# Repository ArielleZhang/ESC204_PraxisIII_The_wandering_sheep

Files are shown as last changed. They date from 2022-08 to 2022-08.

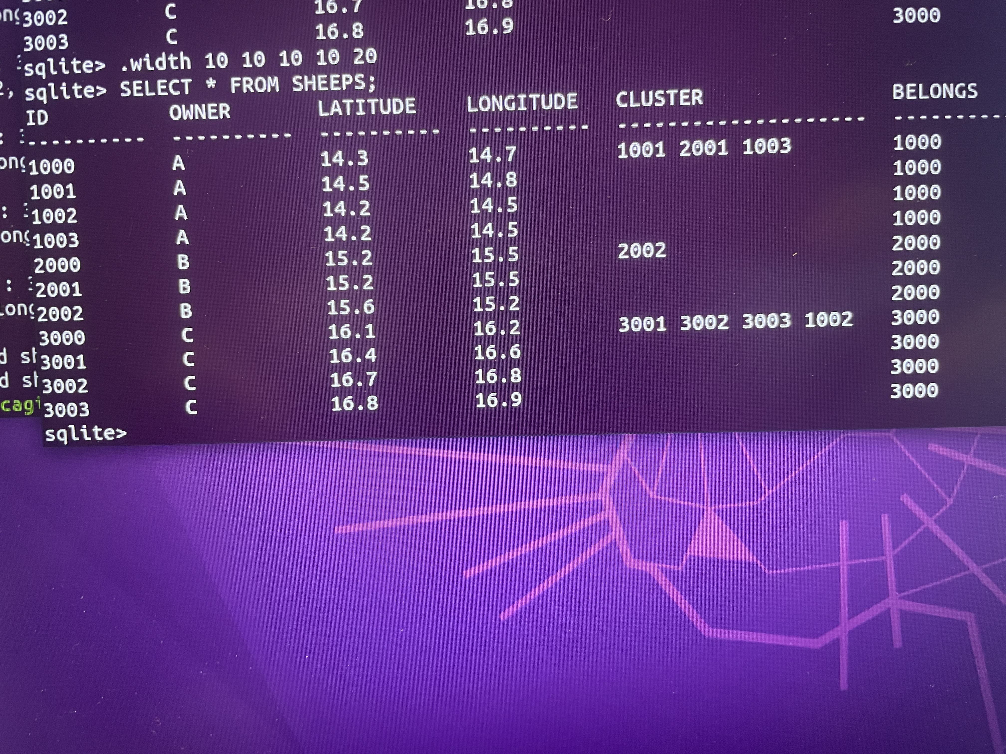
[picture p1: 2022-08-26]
Design Milestones/Prototype/Back End/Second Version/database_pic.jpg

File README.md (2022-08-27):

# ESC204_PraxisIII_The-wandering_sheep

Design considerations
The wandering sheep project implemented the "Improving GSM-based sheep tracking: Using a cluster-based multi-hop approach" paper to develop a cost efficient but accurate sheep tracking system for residents in Rosedale, Mthatha, South Africa.

## Electrical requirements
1. Go to /Follower Sheep(Wireless Transceiver), download the adafruit library zip.
2. Add it to the arduino libraries file, open files->examples->adafruit blue fruitLE nF51->blueart_cmdmode.
3. Uncomment the software UART in the code, comment the default SPI code.
4. Download the Blue Connect mobile phone app, connect it to the bluefruit device.
5. Upload to the board and open the serial monitor.
6. If upload failed, check the serial port, make sure it's the arduino UNO port.

## Collar design requirements
1. The CAD model files of the collar design is in /Physical Collar.

## Back end requirements
1. The back end database with an example used in the demo video is in /Backend Database.

## PM documentations and the final deliverables
1. The PM artefacts are in /Team Process (formal checkin documents), and /Housekeeping.
2. There are two main deliverables, the Proposal and the Pitch, relavent documents are in /Design Milestones.

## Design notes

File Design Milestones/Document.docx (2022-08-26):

MAX 12 Pages + 5 appendix + 3-5 team description + bill of material 12 points, times new roman, 1.15, number all pages‼!

## Table of Contents:

I. Executive summary
II. Introduction
III. Background
  a. Scoping
  b. Team Values
  c. Reference Designs
  d. Requirements model
IV. Design Process
  a. Key Decisions for Conceptual Design
  b. Key Decisions for the Prototype
  c. Verification (backend testing cases table need to be edited)
  d. Validation
  e. Reference Designs
  f. GSU reflection
V. Discussion of the Final Outcome (need to cut length and edit)
VI. Conclusion

Appendix I. Teams (Emre’s team member description)

Appendix II. BOM

References

## I. Executive Summary

In Mthatha, South Africa, many farmers face problems with missing sheep. It is tedious work to look for the missing sheep as neither the shepherds nor the farmers have cars and information on where the sheep are. Therefore, they are looking for a cost effective solution to make finding missing sheep easier. As a team, our values are empathy, sustainability, functionality, and accessibility. Our scope was to make a reliable sheep tracking system that is accessible to everyone from the community to prevent the sheep from wandering off or mixing with other flocks. When addressing this opportunity, we prioritized the perspective of the stakeholders. In the opportunity overview, it was stated that “The livestock owners would benefit from a cost-effective solution to track their animals and find them when lost.” Stakeholder analysis gives us the two prioritized objectives: cost efficiency and functionality to track the sheep. The prioritization of these two values scoped out alternatives such as geo-fencing and thermal imaging with drones. Because fencing lacks the functionality to track sheep and thermal imaging with drones has excessive cost that cannot be afforded by the stakeholders. In the end, we decided to use Global System for Mobile (GSM) and Global Positioning System (GPS) to track the sheep with a clustering system which satisfied both of our prioritized objectives. GSM allows for transmission of data through a 2G cellular network, which was chosen since the infrastructure exists to support this system in Rosedale. We divided the flock into small groups, called clusters, with each cluster having a leader sheep with a GPS tracker to locate the cluster. Each leader sheep pings the followers within the cluster based on the Received Signal Strength Indication (RSSI), and the followers reply with their ID which is unique for each sheep using the wireless transceivers. After getting each follower sheep, every leader sheep sends the information to the database using GSM. The clustering algorithm is used to detect missing sheep, and if there are any, those sheep will be displayed in the User Interface (UI) with their ID, the most recent location and missing time. The customized color and engraved sheep ID on the tracker allow the stakeholders to easily identify and differentiate their sheep when looking for them. Our design made a delicate balance between cost efficiency and functionality by reducing the GPS modules needed, assuming that most of the leader sheep will be evenly distributed among the flock.

-add sustainability stuff

## II. Introduction

Small sheep owners in the small town of Rosedale, Mthatha are struggling with retaining their sheep. As livestock farming plays a major role in their economy, losing sheep is critical [1]. There are several situations where a sheep could get lost; They could simply wander off, get mixed up with different owners’ sheep, or could not be taken care of due to the absence of shepherds. Therefore, we and the stakeholders are seeking a solution that has reliable functionalities to track the location of lost sheep such that the loss can be prevented. Here, as the stakeholders include sheep owners and shepherds, the solution must be accessible in terms of cost (one of the most emphasized requirements by the stakeholder), portability, and ease of learning. Furthermore, as our team values sustainability as required by UNSDG 12, therefore a design with a responsible consumption and production process that is durable is also preferred.

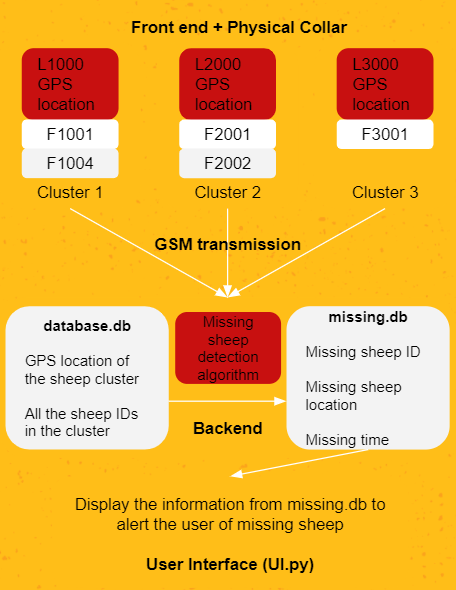
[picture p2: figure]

Figure 1 Sheep_Link conceptual design flowchart

The final proposed design is Sheep_Link, an accessible and reliable Global Positioning System (GPS) Global System for Mobile Communication (GSM) missing sheep tracking system to prevent sheep loss. The system includes electrical GPS GSM tracker collar, backend database and frontend UI. To balance between the two most highlighted high-level requirements by the stakeholders: cost efficiency and functionality of location tracking, we decided to use cluster tracking method. There are two types of sheep trackers for each sheep, leader tracker and follower tracker. Each tracker stores a unique sheep ID: leader’s ID starts with an F, and follower’s ID starts with an L. Both types have wireless transceivers but only leader sheep has GPS GSM module to gather the location and transmit information to the backend database. When updating, leaders ping nearest followers based on the Received Signal Strength Indicator (RSSI), and followers respond by sending their IDs to the leader. Leader sends all the cluster IDs and its own current GPS location to the backend database. The cluster size is customizable depending how many leader trackers the user wants, having smaller cluster size provides more accurate location tracking with a trade-off to be a higher cost because GPS GSM module is the relatively expensive part of the tracker. Backend clustering algorithm will send missing sheep alerts including missing sheep location and missing time through the User Interface (UI) whenever a missing sheep is detected. Also, keeping the UNSDG 12 in mind, we designed the physical tracker to be using recyclable polymer [2], and rechargeable batteries

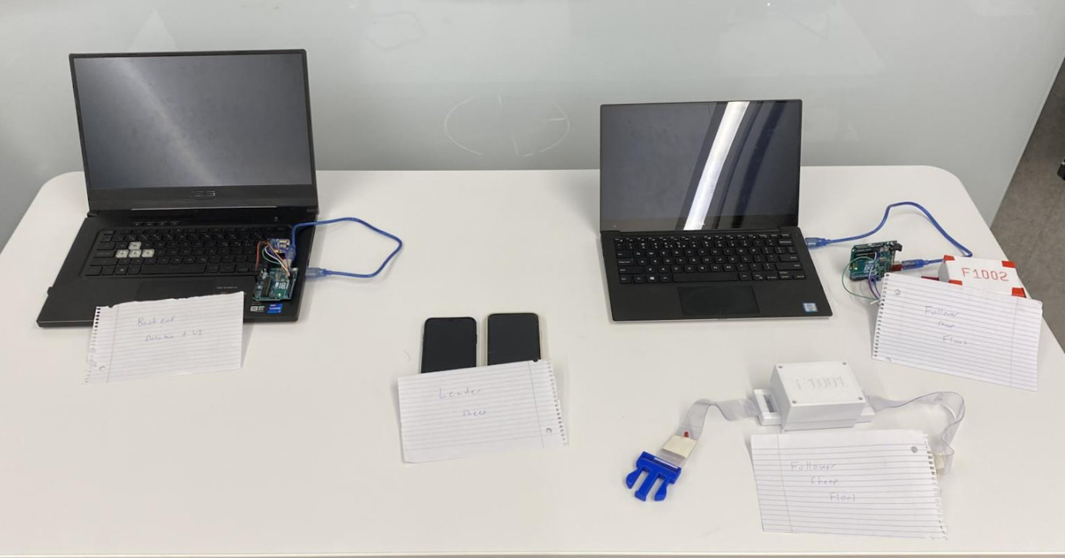
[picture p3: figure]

Figure 2 Final prototype of the trackers and the backend

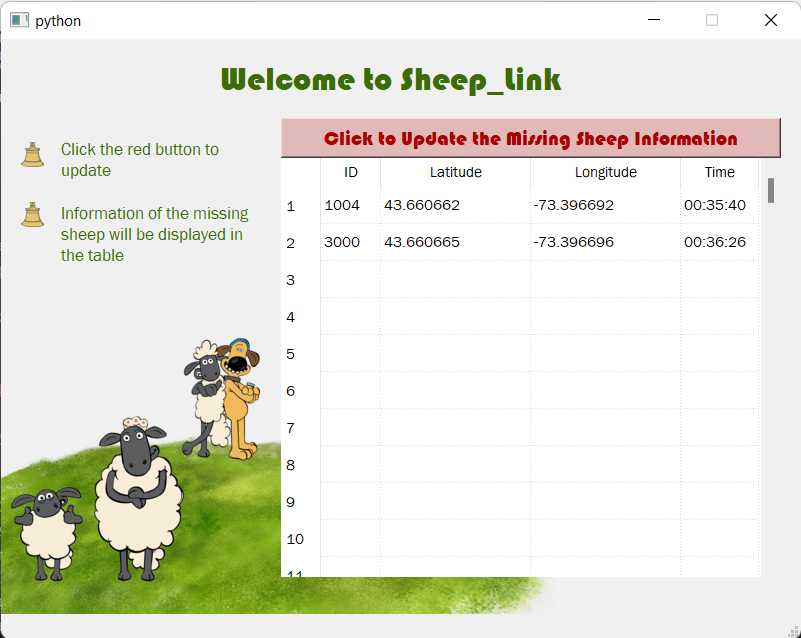
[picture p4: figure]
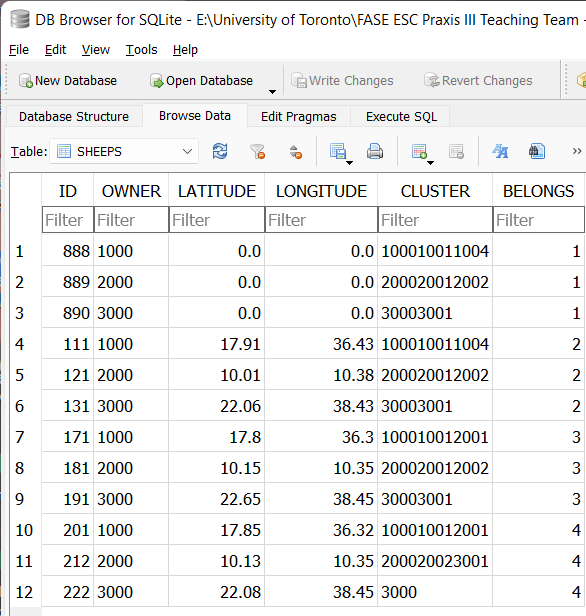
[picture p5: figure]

Figure 3 Final prototype of the UI and backend database

We prototyped two fully functional follower trackers (F1001 and F1002 in Figure 2) with Bluefruit LE UART Friend and Arduino UNO R3. F1001 is powered by a 9V battery, and it has a complete case concealing the electronics with an adjustable belt strap. F1002 is powered by the laptop. With the available components in MyFab, we could only use Bluetooth transceivers with UART protocols. However, Bluefruit comes with a phone app that supports multiple UART modes, allowing us to ping several follower trackers at the same time. The GPS location of the phone is also available on the Bluefruit app. Therefore, we decided to use the phone as the leader sheep although there are other choices for us to proxy. Because the Bluefruit app is the best possible representation of the system. After being pinged by the leader, F1001 and F1002 will send their IDs to the Bluefruit app via UART. Since GSM module is not available in MyFab, we proxied by manually sending the received follower IDs and the GPS location to the backend database (the left laptop in Figure 2) also using the Blurfruit LE UART Friend. The backend database and UI (Figure 3) is fully developed using SQLite and python. The algorithm can detect both missing leader and follower. The UI displays all important information including missing location and missing time of the missing sheep. The UI is also designed for better accessibility: available in both English and Xhosa and requires no technical training. The final prototype for one collar costs us: Arduino UNO R3 ($24.95) + Bluefruit ($17.50) + Battery ($3.7) + 3D printed tracker case and collar strap ($3.50) = $49.65.

1. (Ethan)Select Background Details (we could copy and paste from the proposal for this part)
  a. Understanding the stakeholders:
    i. Who is affected and how?
    ii. What is the value for stakeholders?
  b. Defining the scope:
    i. What are the limits to what we can do (and not do)?
    ii. What is the primary goal of your team’s design? Provide details explaining the value proposition of your team’s design (i.e., benefits to the stakeholder and how these relate to the UN Sustainable Development Goals.[1])
  c. Describing the service environment:
    i. What is the situation in which it must work?
    ii. What additional considerations and/or complications are added by the environment?
  d. Describe previous approaches to providing value in this or similar contexts:
    i. Making reference to previous solutions, reference designs, and literature.
    ii. Examining what was previously tried.
    iii. Assessing how well did it work.
  e. Are there specific standards or details that any solution must meet?

## III. Background

## Stakeholders

The sheep owners in the rural town of Rosedale, Mthatha are the primary stakeholders. The main factors that affect the stakeholders are the economic impacts due to the lost sheep, the effort required on their end for finding the sheep, and the accessibility of the product. The three corresponding values are economic, convenience, and accessibility. The stakeholders wish to secure their profit by finding the lost sheep, so it would be illogical to spend more funds on finding sheep compared to the gain. Furthermore, tracking the lost sheep takes effort on the owners’ end as currently, they need to search the vicinity usually 1-2 km away or nearby homesteads up to 5 km away without cars. Therefore, functionalities such as accurate tracking and locating of the lost sheep can bring the value of convenience to the stakeholders. Lastly, to maximize benefits for most sheep owners, accessibility is highly valued. Considering the technical abilities of the shepherds, implementing the solution should be easy for the shepherds to handle. In this proposal, we prioritize the needs and values of our primary stakeholders; however, secondary stakeholders such as shepherds and sheep are also important. The shepherds are underpaid and are often given a high workload; thus the owners have a precarious relationship with the shepherds. Reducing the shepherd’s workload by introducing high functioning designs that can motivate them to work, would secure the owners’ money by minimizing the chances of sheep getting lost. For the sheep, the solution should not reduce the economic value of the sheep both directly and indirectly, thus the solution should not harm the sheep.

## Scoping

With the internet and mobile network coverage, the assistance of shepherds, and the limitations on funding, our scope is to develop a reliable sheep tracking system that is accessible to every community member in Rosedale, which can prevent sheep from wandering off or mixing up with other flocks. The focus of the design will be its reliability to prevent the sheep from wandering off and its feasibility of being integrated into the daily lives of the shepherd.

## Team Values

Our teams had three main values that will be incorporated into the requirements model: Functionality, Accessibility and Sustainability. Functionality is one of the main priorities of the design since the shepherds are looking for a design that will address the issue of wandering sheep. This will include tracking capabilities and a system that is accurate and accounts for all possible instances of sheep wandering off. Additionally, in our teams’ values, we incorporate empathy into the design in the form of accessibility. We focus on making the product accessible to everyone in the community by keeping the cost affordable and making it easy to learn and operate. Aiming to make the system highly automated and user-friendly streamlines the training process, providing ease of learning for shepherds and sheep owners. In keeping with the 12th goal of UNSDG, sustainable consumption and production in mind, we aim to make the design durable to improve resource usage efficiency. The extended lifetime of the product reduces the cost for the stakeholders and is identified as responsible consumption promotion.

## Reference Designs

Fencing (sometimes electrified) is a popular option for animals wandering off problems. Fencing an area is simple and effective to prevent animals from leaving by creating a physical barrier. However, for our stakeholders, it is not a valid solution. Because many shepherds in Rosedale share a communal grazing area, the coordination of fencing would be complicated, and fencing would reduce the amount of grazing land the shepherds have. Price estimates to be 7500 – 15000 USD (9500-19000 CAD) for the amount of grazing land the shepherds have, which is very expensive when compared to the price requirements provided later [3]. Taking fencing as a reference design, the cost of our solution should be lower than this. Another option that has been used to find sheep is GPS tracking. This has been used for sheep tracking in countries such as Norway [4]. The Telespor system is the current “market-leading" solution and makes use of a GSM to locate sheep in real time. However, this is also costly at 290 CAD per sheep, with no flexibility since each sheep’s collar will make use of GPS technology [5].

## Requirements

The requirements model was developed to fulfil the needs of our stakeholders by successfully preventing sheep loss and ensuring that the design would be feasible to integrate. We incorporated our value proposition by deriving the high-level objectives from the three values. From each high-level objective, we developed detailed objectives to be our specific testing protocols. We will first verify each subsystem of our prototype to ensure that there are no errors or malfunctions, and then will validate the design by either physically testing is possible or otherwise theoretically predicting the outcome against each proposed requirement to holistically assess to what extent our design delivers the values to the stakeholders.

Functionality

Location Tracking

The primary functions of the design should include a lost sheep notification system and finding system to fully address the missing sheep issue. The first functionality requirement is that it must track the location of the sheep.

Table 2 Criteria, metrics, and constraints for the finding system

Criteria: tracking range
Farther is better (m) | Must ≥ 2000 m. Should ≥ 5000 m

Criteria: location accuracy: closeness of a measured location to the real location of the device at the time of measurement [6]
The closer is better (m). GPS level accuracy is within 4.9m[7]. | Must not exceed 20m to provide an accurate location of the sheep

Reliability

Reliability requirements make sure that the design can handle the different cases of the sheep wandering off, and that the shepherds can be notified within time to prevent the sheep through action.

Criteria: reliability of the notification communication

Lower percentage error of false alert (%)

Must not be interrupted and interfered with when transmitting messages.

Should allow notification documentation, record all the history notifications [8]

Accessibility

Affordability

The requirement that was emphasized the most by the primary stakeholders was cost-efficiency. The stakeholder provided an ideal cost of 150 * 12 CAD = 1800 CAD for the final product. However, recognizing the challenge to implement solutions with high functionality to accurately and reliably track the sheep's location, we justified cost constraint of the final design to be less than 3400 CAD because the average purchase price of the sheep in South Africa is approximately R1,300 and the average sheep output of small livestock owners is approximately R3,000 [9]. The average profit efficiency of the sheep was estimated to be about 65.5% [9]. Therefore, the strict profit made by each sheep can be estimated to be around R2,000. On average, small livestock owners have 150 sheep, and the rates of sheep loss has an average of 8% [10]. Hence, the minimum loss would be about 12 sheep. Therefore, we set the constraints for the budget to be (the strict profit each sheep makes + the price of the sheep) * (the number of sheep that get lost) as the design should be profitable in the end. Therefore, our hard constraint is that our design must not exceed (R2,000 + R1,300) * 12 ≈ R39,600 = 3410 CAD per year.

Portability

As part of the design for travel and ergonomics, the solution needs to be able to move around freely to track the sheep at different locations. Portability requirements for handheld devices were taken from the 2005 US human factors guide for the design of handheld devices. Two of the main concerns for devices are the weight and dimensions of the device. Note that the dimensions of the device are specified as the stow-away size; some devices may unfold but must stow away to a good size.

Table 3 Criteria, metrics, and constraints for portability

Criteria: Device needs to be easy to move around, and shepherds must be able to use the device over the range of the grazing area (~5km through hilly terrain and villages).
A lighter device is preferred (weight in pounds) | Widgets should be under 5.1 pounds if handheld. [11]
A smaller stowaway volume is preferred (size of dimensions in mm) | Widget should stow away to under 100x125x255mm in size [11].

Ease of Learning

The product should have the option to display information in the local language Xhosa [12]. Since the solution will be implemented with local shepherds, there also needs to be education in teaching them how to use the design solution. The less time it takes for the shepherds to learn how to use the design the better. This will depend on the quality of the user interface and should contain features such as one-click information finding and intuitive graphics.

Sustainability

UN SDG 12: Responsible consumption and production

Responsible consumption and production objectives relate to the materials used for the physical collar [13]. The goal is to use materials that have the smallest carbon footprint and can be recycled if the product were to be taken apart. An additional consideration is the impact of the battery, using rechargeable batteries instead of lithium batteries reduced soil and air contamination [14].

Durability

High durability reduces product costs for the stakeholders by reducing the amount of maintenance needed. Besides the cost, durability also encourages responsible production by increasing resource efficiency. Considering the grazing area is close to water sources, the product needs to be waterproof, dustproof and drop proof.

Criteria: Device needs to work for an extended period without malfunctioning

The lifetime of design [15]

Must pass waterproof and dustproof test from IP5 to IP6 [16]

Must pass drop test for ANSI/ISEA 121-2018 [17]

Working at least two weeks without charging [18]

2. (Arielle)Design Process and Key Design Decisions
1. (Arielle)The path to development of the prototype:
  a. Insights into the presented conceptual design that were gleaned from the prototyping process.
2. (Ethan) Comparison to previous approaches (i.e., reference designs) (i.e., tell the audience why your solution is an appropriate choice in relation to the reference designs).
  a. Mention geofencing, the GPS TLS tracker, RFID scanning, paint/collar

## IV. Design Process and Key Design Decisions

In our project management plan, the team is divided into three divisions: hardware of the tracker, physical design of the collar, and software, which include the backend database and front-end UI. Three engineers from our team are assigned to be the lead of each division, and deadlines for design milestones are set to check the progress of all three divisions and merge the work.

Key decisions for the conceptual design:

1. Use GPS to track the sheep's location:

As required by the stakeholder, they would like to track the exact location of the missing sheep. We interpreted the latent need behind this requirement to be the need to minimize the effort spent when searching for missing sheep. GPS is used to monitor the sheep’s location all the time and notify the shepherds once the sheep leaves the cluster. Notifying the shepherds, the exact location of the wandering sheep before it goes too far away allows the shepherds to efficiently target the wandering sheep and get it back immediately, which reduces the workload. Thus, we believe it is the best solution that satisfies the stakeholder’s needs.

2. Use clustering methods to reduce the cost:

However, the tradeoff for using such expensive GPS trackers is the excessive cost. The stakeholders not only value functionality, but also value cost efficiency. However, we recognized the conflict in satisfying both. The clustering method we introduced in section__ leaves the choice of whether to be cheaper but have a larger location uncertainty or to have a smaller location uncertainty but be more expensive to the stakeholder. (add details about the clustering calculation?)

3. Use GSM to transmit information:

From the context provided by the stakeholders, the town of Rosedale has mobile phone coverage. Furthermore, research has shown that Mthatha has full 2G GSM coverage provided by Vodacom, Telkom, and MTN [19]. GSM network is significantly cheaper than Wi-Fi, 3G, 4G, and 5G networks and therefore reduces the cost. Here, it should be noted that as great as GSM is for increasing affordability, this is in exchange for the speed of the connection. Since the current market is working with the 5th generation of digital networks, GSM being the 2nd generation implies its lack of rapidity. Nevertheless, as 2G network is still integrated into our daily lives, the connection speed is sufficient for this application and if the stakeholders wish for a faster connection, a simple upgrade in the network to 3G or higher is all that is needed.

4. Accessibility of the UI:

To make the product easy to use for the shepherds and sheep owners, we designed the UI to have both English and Xhosa versions. Also, the one-click-to-update feature is very user-friendly, requiring zero technical training.

To demonstrate the full functionality of the conceptual design, we decided to prototype both types of the trackers, the physical collar, the backend database with the UI. These are the three main tasks for the three divisions in our PM plan.

Key decisions for the prototype:

1. We fully prototyped one battery powered follower tracker with the hardware concealed in the complete physical collar to demonstrate the design concepts. The second follower prototype is only powered by the laptop to save batteries (practicing UNSDG 12 responsible production). We decided to prototype two followers because we need to test the clustering functionality based on the RSSI strength.
2. We decided to use Bluefruit Connect phone app as the leader sheep because the app has multiple UART mode, accurately representing the idea of leader sheep calling multiple follower sheep at once. Furthermore, the app allows us to acquire the GPS location of the phone, representing the GPS module to be implemented in the product. The leader communicates with the backend using Bluetooth, which is a proxy of the GSM transmission because MyFab does not have a GSM module. Then we need to manually send the information (GPS and the collected follower IDs) to the backend.
3. We fully prototyped the backend database using SQLite and Python and prototyped the UI using PyQt5. We chose to use database because compared to txt files and excel, SQL database is the most efficient way to store and handle large number of update messages because we need to use python to extract write information into the database to detect missing sheep. We chose to use PyQt5 to write the UI because it is intuitive and widely used.

Influence of Reference Designs on Process

The most relevant reference design that influenced our thinking as a group was the Telespor system from Norway mentioned earlier in the reference design section. The main drawbacks of the solution that made it unsuitable for our opportunity was that it is costly and would be hard to integrate into the shepherd’s operation due to language constraints (the Telespor system is not offered in the local language Xhosa). Our design addresses these two issues by offering flexiblity on how many GPS modules to include, lowering the price point. Additionally, we have designed our UI to be usable in many languages including Xhosa and features such as one-click updates ensure that the design is accessible to the shepherds. However, our design is not as developed as the telespor system, and further improvements on battery life and design of the leader sheep’s collar may increase the price of the design.

Verification

To ensure the high-fidelity prototype is functional, reliable and error-free, we tested each subsystem with repeated trials. We did not integrate the trackers and the backend database because we do not have the GSM transmission module. Using the Bluefruit and the Bluefruit Connect phone app to proxy does not allow the collected information to be automatically sent to the backend.

Electronic Subsystem

To test the electronic pinging system, we needed to test three components:

1. Whether RSSI range can be used for clustering
2. Pinging the sheep and how it responds with the identification number
3. The feasibility of powering the system and running the circuitry with the 9V battery

Testing of the RSSI was done through graphing the RSSI against distance. Through experimentation, it was found that the RSSI strength decays in a non linear fashion.

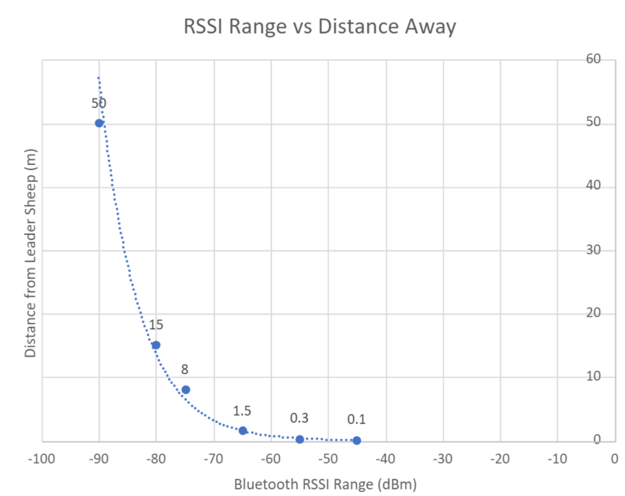
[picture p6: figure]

From this testing, we found that RSSI strength works for clustering, but becomes very unreliable at longer distances since the signal strength falls off quickly. The next set of verification tests we performed are the different cases of pinging sheep. After setting up the follower sheep collars, we used the Bluefruit app to test if we can ping both sheep, and each individual sheep (simulating the case where the other sheep is out of range).

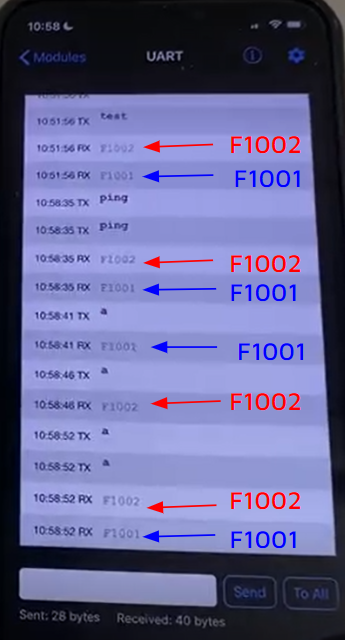
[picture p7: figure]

The results of the test showed that we could ping multiple sheep using the multiple UART function of the app, which gave us confidence in our final design, since we are able to ping all nearby sheep with a single message. Lastly, the arduino was sufficiently powered by the 9V battery and supplied constant power throughout our 1 hour testing sessions. This showed us that the battery life of the prototype was adequate, and can be improved through further research and development.

Physical collar

1. The base of the tracker perfectly fits the Arduino (Figure_), and the Bluefruit and the battery are “soldered” or taped onto the second layer. These all prevent the electronics from moving inside the case even when shaking and/or dropping to the ground from 1-meter height (the standing height of a sheep).

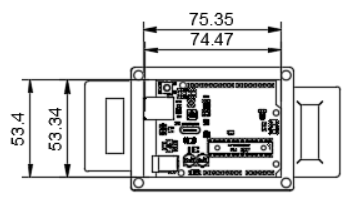
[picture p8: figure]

2. The hardware was found to be fully waterproof such that the tracker inside was safe from any damage when proxy waterproofing in the form of rubber bands was added. This was tested by putting tissues inside the cover and sinking it under water for 2 hours, following the test for waterproof and dustproof level IP5 and IP6.
3. The engraved sheep ID in 3D printing is clear and easy to see.

Backend Database and Clustering Algorithm

The backend algorithm passed all testing cases that would be encountered: no missing sheep, missing follower sheep and missing leader sheep. We created a three-leader sheep flock for this testing, therefore there will be three data entries into the database for each update.

Table 1 Initialized leader sheep and clusters

Leader Sheep ID | Cluster Sheep IDs | Case 0 initializing the database Algorithm output: no missing sheep.
1000 | 1001, 1002, 1003, 1004, 1005
2000 | 2001, 2002, 2003, 2004, 2005
3000 | 3001, 3002
1000 | 1001, 2001, 1002, 1003, 1005 | Case 1: 2001 and 1004 changed clusters Algorithm output: no missing sheep.
2000 | 2002, 2003, 2004, 2005
3000 | 3001, 3002, 1004
1000 | 1001, 2001, 1002, 1003, 1005 | Case 2: missing follower sheep when it leaves the flock Algorithm output: missing sheep 1004, the most recent GPS location of the cluster (sheep 3000’s location), and the missing time.
2000 | 2002, 2003, 2004, 2005
3000 | 3001, 3002
1000 | 1001, 1002, 1003, 1004, 1005 | Case 3: missing leader sheep when it has an empty cluster Algorithm output: missing sheep 3000, the most recent GPS location of 3000, and the missing time.
2000 | 2001, 2002, 2003, 2004, 2005, 3001, 3002
3000

User Interface

The User Interface is a python file, after running, the UI will pop up with a clickable button allowing the user to manually refresh the page. The UI automatically reads the output of the backend clustering algorithm from another database that stores the missing sheep information. One shortcoming of the database is that it does not automatically refresh.

Validation Chart

To ensure the high-fidelity prototype is delivering the values (functionality, accessibility and sustainability) we would provide to the stakeholders, we assessed and/or tested the prototype against each detailed objective.

Functionality

Criteria: tracking range

GPS has global coverage, allowing sheep to be tracked anywhere in the world.

Criteria: location accuracy: closeness of a measured location to the real location of the device at the time of measurement [6]

The leader trackers have GPS level accuracy which is within 1m < 20m [7].

Depending on the number of leader trackers the follower tracker location uncertainty is:

Max location uncertainty = 150 / (16% leaders *150) * 2m + 1m = 14.5m < 20m

Min location uncertainty = 150 / (50% leaders *150) * 2m + 1m = 6m < 20m

We assumed the sheep activity range when grazing is 2m [20] and the worst-case scenario is all sheep stand in a row forming a linear cluster.

Criteria: reliability of the notification communication

Since the sheep are clusters based on the RSSI, and RSSI sometimes is not a perfect estimation of distance. Our testing result has a 20% fail to report rate when the follower tracker’s distance from the leader sheep is already further than the calculated cluster radius but it still does not disconnect.

Bluetooth wireless transceiver and GSM both have stable, reliable signal.

The backend database is implemented in SQL, allowing to store large number of updates.

Accessibility

Criteria: low cost

Depending on the number of leader trackers the follower tracker location uncertainty is:

Max cost with 16% leaders: 125*12.93 CAD + 24*17.28 CAD = 2030.97 CAD < 2300 CAD

Min cost with 50% leaders: 75*12.93 CAD + 75*17.28 CAD = 2265.75 CAD < 2300 CAD

BOM for each leader tracker and follower tracker is in Appendix II.

Criteria: Device needs to be easy to move around, and shepherds must be able to use the device over the range of the grazing area (~5km through hilly terrain and villages).

Tracker is 0.22 pounds < 5.1 pounds.

Tracer is 85x70x45mm < 100x125x255mm in size.

Criteria: Ease of Learning

The UI has both English version and Xhosa version and is easy to use with no prior experience and/or training needed.

Sustainability

Criteria: UN SDG responsible consumption and production

The design can be fabricated using recyclable polymer PET [21] and rechargeable batteries.

Criteria: Device needs to work for an extended period without malfunctioning

The design can be designed to pass waterproof and dustproof test from IP5 to IP6 [8].

The design can be designed to pass the drop test for ANSI/ISEA 121-2018 [21] by soldering all the electronics onto the surfaces and using shock absorption polymers [22].

The design can use rechargeable batteries that sustain two weeks without charging [10].

GSU reflection

The GSU student provided us with new perspectives to include a broader range of stakeholders, such as the local government, local environments, and local businesses. We incorporated these considerations into our design by making our design more sustainable by using green materials and rechargeable batteries to protect the local water-dam environment and comply with local government environmental regulations. The material that we can use is PET which is a representative of recyclable polymer. PET is a clear, strong, and lightweight plastic [23] that can be used as the material for the case and can be able to pass the drop test and protect the inner modules. PET is fully recyclable, and it is the most recycled plastic in the U.S and worldwide [23], so this material can support us to pass the requirement of UN SDG12. In addition, the GSU student asked us if there will be any alternatives in case of technical difficulty, addressing this issue, we recognized that it is risky to assume fully reliable 2G GSM coverage in Rosedale without further research. Research shows that near the water dam, Rosedale is not fully covered by sable 2G nor 3G/4G networks. Research tells us that in the future we can implement a hopping algorithm [] to solve this problem if at least one sheep is in the 2G GSM coverage.

3. (Edwin) Discussion of the Final Outcome (Design and Prototype)
  a. Why your conceptual design is a valid solution to the identified stakeholders needs that provides value, making links to your value proposition.
  b. What limitations and assumptions your team made while deciding on your final design and prototype. (Ethan, Edwin, Emre)
  c. How your team’s prototype relates to the design concept and how the prototype provides insight into the feasibility of your design. (Ethan, Edwin, Emre)
  d. How your team worked together to create this final prototype.(PM plan, look at the presentation PM plan)

With the provided context of finding wandering sheep in Rosedale, Mthatha, our proposed design Sheep Link prevents sheep wandering by tracking the GPS location and notifying the shepherds before a sheep wanders off too far. Because it is tedious for the shepherds and the sheep owners to find the sheep when they wander off too far away due to their lack of cars. By analyzing the stakeholder’s explicit and latent needs, our value proposition is summarized with three key words: sustainability, functionality, and accessibility. Our product successfully delivers these values by satisfying the corresponding requirements. The requirements for functionality are location tracking and reliability, the requirements based on accessibility are affordability, portability, and ease of learning, lastly, the requirements for sustainability are durability and UNSDG12. This tracker can reliably track the wandering sheep’s GPS location, integrating with the engraved sheep IDs on the physical collar and their customizable colors, sheep can be easily differentiated from other owners. Also, Bluetooth signals are stable even if there are obstacles. The accuracy of the tracker depends on the number of leaders the owner selects. Our product can satisfy all the requirements from the value of functionality. There is a small issue for affordability since if the owners want accuracy, they need to make some sacrifices in pricing. The more leader collars, the more accurate the tracker can work, but the leader collar is about $20, so the owners need to decide on what kind of performance they want based on the cost. Lastly, for sustainability, we use a rechargeable battery, and we select durable and sustainable materials for the case. We fulfill the UN SDG 12. Our design of the case passes the IP6 test for waterproof and dustproof by easy sinking tissues test, so basically, our design is a valid solution to the problem of wandering sheep

(b)We assume cell phones as our leader sheep and laptop as our database. We have consistently completed the design of follower sheep by using the Arduino as the main module, and the data of the follower is transmitted to cell phones which are the leader sheep by Bluetooth since we cannot work with modules for GSM and GPS, and we use Bluetooth as a backup plan for transmitting data. There are not any limitations to the collar design, and we assume the materials that we apply are green materials that are recycled polyester. For the electronics of the system, the main limitation is the battery life of the prototype. Since we as a team did not have access to rechargeable batteries, we powered the collar using a 9V battery which has a lifetime of around 24 hours when powering an arduino board. For the backend, we assumed all the stakeholders has access to an electronic device capable of running SQLite databases and has PyQt5 library for the UI.

(c)For the collar design, it is the exact shape we want for the actual product, but the dimension of the case should be changed when we apply the design to the final product. The priority of the case is to protect the modules inside and pass waterproof and dustproof. The three layers design is what we want for the protection of the GPS GSM module on the bottom layer, and the middle layer is used to make users easy to recharge the batteries. The two ears design is the connection part between the sheep, and our product can make sheep feel comfortable by the application of adjustable stray. The product is safe for both sheep and users since there are no sharp edges on the case. The backend of the system is tested using real life scenarios where we fed data to the backend manually through the BluefruitConnect app. The algorithm was able to report missing sheep correctly in each scenario. The test results show that the algorithm is also likely to work under real life conditions.

The electrical system proxies the design concept by using bluetooth connections to mimic transmitting data over a GSM network. The prototype shows us that the collars need to be constantly running and searching for nearby devices, and this could cause problems if the connection is unstable. Moreover, the necessity for the collar to always be on would also raise concerns over powering the system. Overall, the prototyping has shown that connecting to multiple devices in a nearby network is possible, but more advanced knowledge must be used to scale this to larger networks with unstable connections, and looking into a way to not always have the electronics can help reduce the power consumption of the system and is a path for further development.

Throughout the semester, our team cooperated in a highly efficient and highly functional manner for this project. Arielle is the project manager; she monitors the progress of the project. Tab organizes the folders and documents everything. Yiqun is responsible for the procurement and budgeting. During the prototyping phase, there are three divisions, Ethan and Arielle are electrical engineers for the hardware division, developing the circuits for the tracker. Emre is the software engineer for the software division, developing the database and the UI. Yiqun is the mechanical engineer for the collar design division, designing the physical collar. Tabitha researched for the application of GSM and 2G network, which is the only part of our system that we did not prototype due to limited access to resources. We update each other weekly in our group chat, and design milestones are set to integrate and merge the works from all three divisions.

4. Conclusion and/or Next Steps
  a. Your value proposition in relation to the context, your design that is intended to realize that value proposition, and how these may be refined in future iterations of the design cycle. (Arielle)
  b. (Ethan, Edwin, Emre)How the current prototype supports your arguments about the validity of your design.
  c. What your suggested next steps are to further develop your design concept, including what other tests could be done with the current prototype and what other prototypes could complement the current one in providing more insights into your conceptual design. (Ethan, Edwin, Emre)

Value proposition:

Develop a sustainable, reliable sheep tracking system that is accessible to every community member in Rosedale, Mthatha.

Team (in the Appendix)

- Team value statement (half page) Tabitha
  - Description of their holistic, team values statement describing this makes them suited to design and build a prototype for the context

Our team values related to this project include empathy, sustainability, functionality, and accessibility. We value empathy which allows us to perceive the stakeholders’ needs and context on an emotional level, making us more passionate about solving the issue. Furthermore, this helps us to more sensibly balance conflicting requirements such as cost efficiency and functionality. Additionally, our value of empathy also connects to considering the environment which aligns with the UNSDGs and leads to our value of sustainability. Valuing sustainability helps us to be more conscious about the production process and lets us seek a more durable and cost-efficient design that matches the stakeholders’ context. Nevertheless, being a team of engineers, our value of functionality is also apparent, making sure that despite us aiming for a sustainable design, the functionality is at its best. We are invested in taking care of all the functional needs of the solution and satisfying the stakeholder's needs. Moreover, we greatly value accessibility which is also rooted in our value of empathy. As we empathize with the financial and educational backgrounds of the stakeholders, we wish to produce a design that is accessible to all stakeholders by being affordable and easy to learn. We as a team truly make every design decision based on our team and the stakeholders’ values, aiming toward the best design. We have developed a precise and rigorous requirements model derived from the values to efficiently and effectively assess all design candidates. As our final design and its prototype have met all values while passing the numerous functionality tests, we believe that our team is suited to continue with this project.

Tabitha is in charge of our team’s research and document management. Furthermore, in terms of the final design, she was responsible for researching and making theoretical applications of the Global System for Mobile Communication (GSM) for front-end and back-end communication. Her research experience in extracurricular design teams, as well as past in-course group work such as Praxis I and II, allowed her to better tackle research tasks. These research skills were also applied to securing the requirements model such that it was rigorous and detailed along with developing testing and verification methods for the detailed objectives. Moreover, highlighting her organizational skills, she was given the role of organizing the Microsoft SharePoint folder and documents. These organizational skills were also infused with artistic skills from previous experiences in graphic design and visual art competitions which helped with her designing the design pitch brochure for the final presentation.

Ethan oversees the integration of electrical components into the final design. This included the setup of the follower sheep Arduino and connecting the bluefruit bluetooth module. The functionality of the follower sheep collar was controlled using C code on the arduino IDE, and linked through the bluefruit app on the mobile phone. His experience with circuitry from past courses helped to get the Arduino system set up, however most of the specifics relating to the prototype had to be learnt from scratch. Additionally, the integration of the battery and research into the possible routes forward in terms of power supply was a key role Ethan took on for the prototype. For the design pitch document, he contributed to streamlining the requirements model, background research and the testing protocols for the collar.

Yiqun is responsible for the mechanical design and budget tracking. In terms of the final design, he builds the 3D design of the collar. His Cading skills learned from last year and practiced during widget labs support him in the tasks of the physical design of the final product. These skills combining the critical thinking of how to fulfill the requirements help him to develop a detailed physical collar. In addition, he keeps on track of the budgets carefully during the whole design process to take notes of every cost and keep eye on the remaining budget to have the team have enough money to complete the task. This knowledge is used when fill the bill of materials since we need to minimize the cost of the actual product.

Arielle is the team’s project manager and tech lead. In Phase A, she was responsible for leading the team to frame the opportunity and explore different viable solutions. Her leadership experience with past extracurricular activities provides her insights in discovering the latent needs of the stakeholders. In Phase B, she continues her project manager role and divided the team into three divisions: hardware, software, and physical collar design. Her rich experience with managing group projects allows her to make the team highly functional by distributing tasks and assigning roles based on everyone’s interests and strength. Furthermore, her experience in hardware research, software projects and CADing makes her suitable for the role of tech lead. She monitors and provides technical help for each division when needed and integrates the subsystems for each milestone to verify and validate the design.

Bill of Materials (in the Appendix) (Edwin)

To help a future design team reproduce and/or learn from your prototype it is important to
provide details on the parts used. The Bill of Materials would have a table with at minimum a
list of parts in the prototype, their purpose, their costs, and (where applicable) links to product
pages or datasheets. It would also provide rationale for choice of parts. You should distinguish
between parts that were acquired using your team project budget and parts that were obtained
as part of Widget Labs (including both parts acquired as part of a lab kit and parts acquired
from Widget Lab Assignment budgets).

Components | Units | Unit Cost | Total Cost | Purpose | Links
Microcontroller plus USB | 1 | $8.82 | $8.82 | control the functions of embedded systems | [24]
Wireless transceiver | 1 | $0.66 | $0.66 | frequency is 2.4GHz, and it is a combination of radio transmitter and receiver | [25]
GPS GSM module | 1 | $4.39 | $4.39 | SIM800 is the module we select since it is cheap, and it is the module that can get the GPS data and transmitted by GSM | [26]
9V battery | 1 | $3.98 | $3.98 | Power up the whole product | [27]
Jumper wires | 10 | $0.1345 | $1.345 | Connect these important technical units | [28]
3D printing | 100 grams | $0.03 | $3 | The design of the collar which is the case for these modules

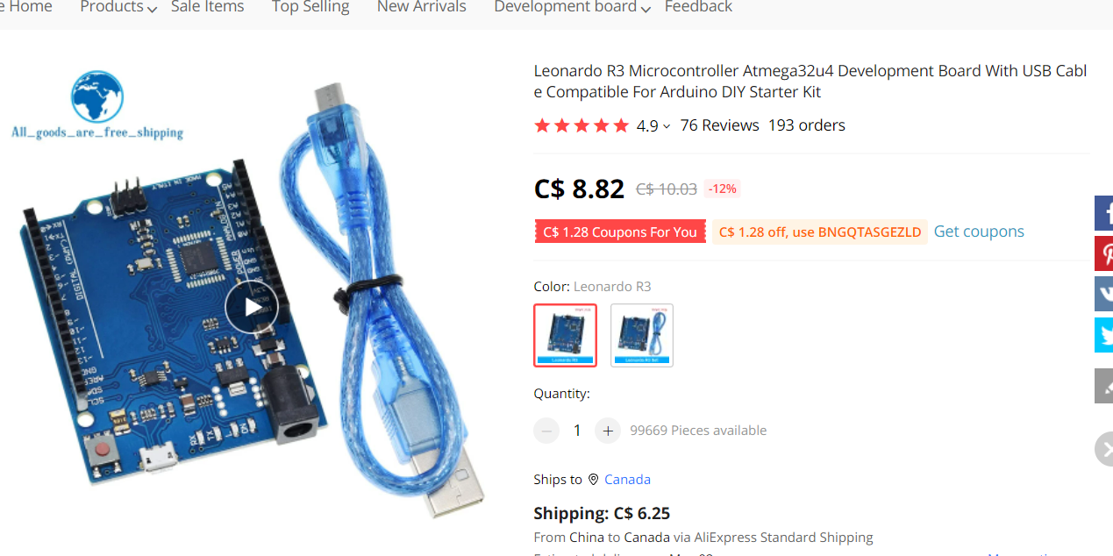
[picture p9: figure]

Microcontroller plus USB and the total cost of them is $8.82

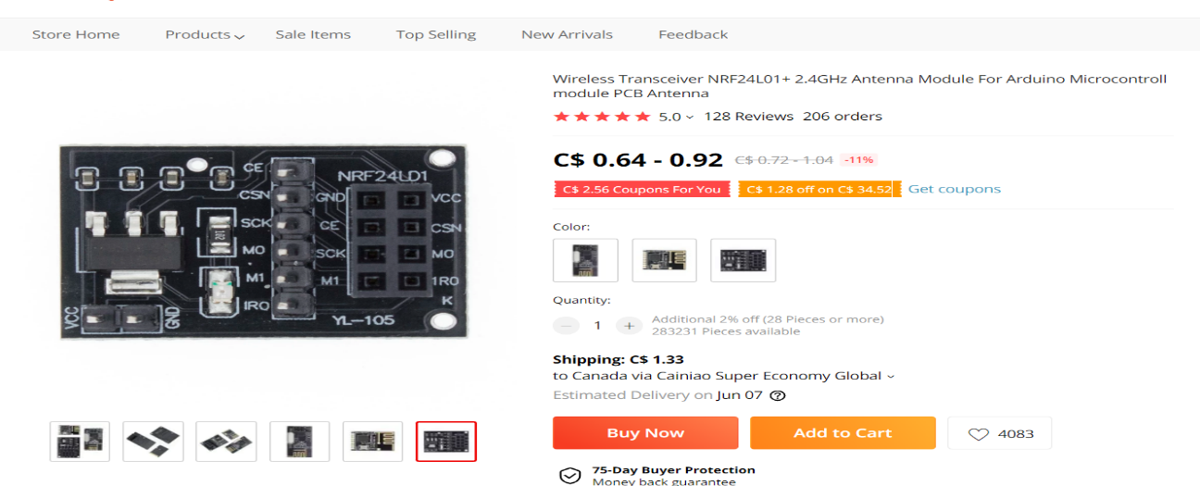
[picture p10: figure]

Wireless transceiver is very cheap, and the frequency is 2.4GHz, and the price is $0.64

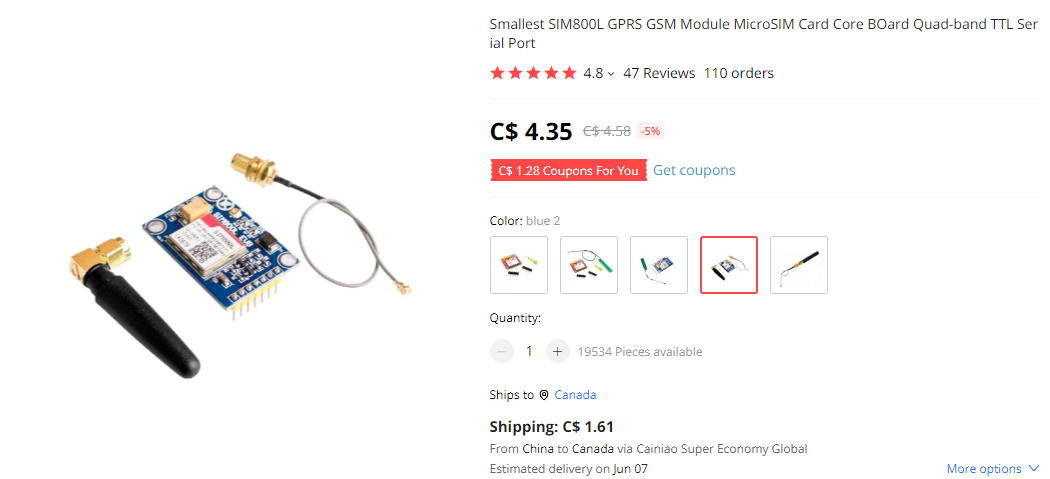
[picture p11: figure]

The GPS GSM module we chose is SIM800 which is $4.35

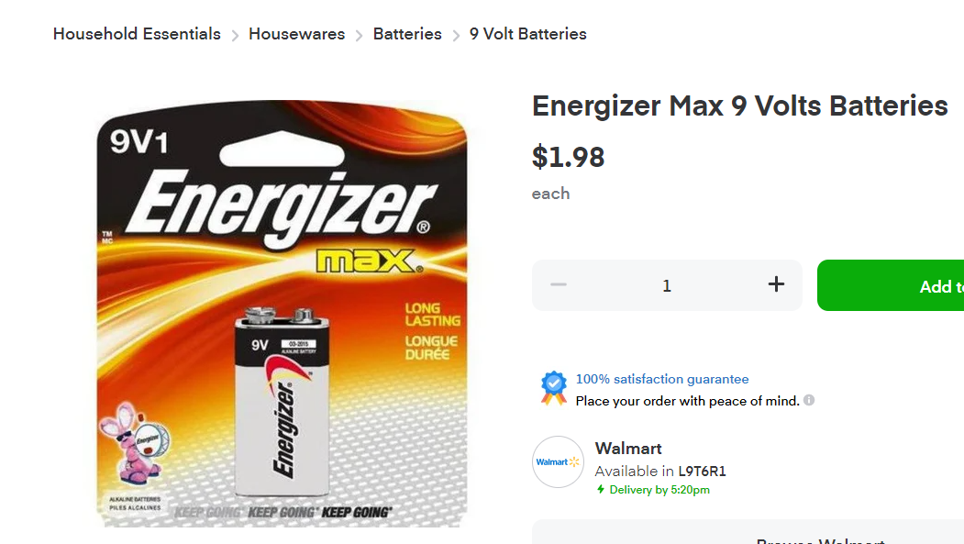
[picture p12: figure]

The 9V battery which is the power source is $1.98

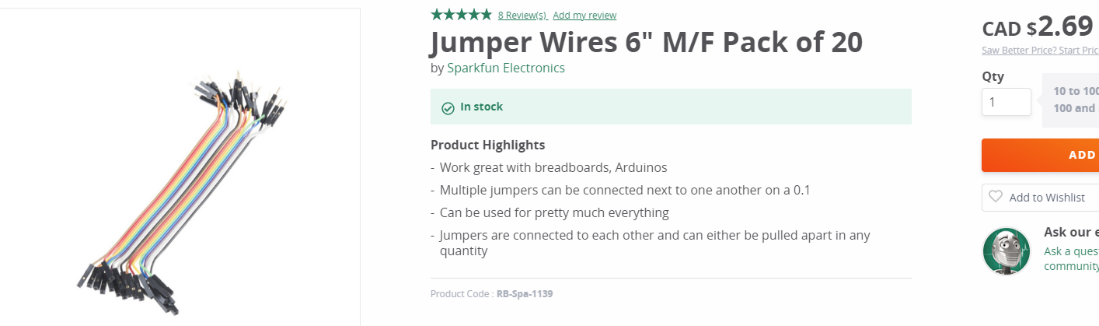
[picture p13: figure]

Jumper wires are cheap, for one wire, it is only $0.1345, each tracker will need maximum 10 wires, so the price is $1.345

The price of 3D printing is cheap since the material of PLA is $0.03 per gram, and the weight of the tracker is 100 grams, so the price for each case is $3.

There is no GPS module in the collar for follower sheep, so the price for follower sheep is $15.785 and the price for leader sheep is $20.135. The price is a little higher than what the stakeholders desire, but the reason why we want GPS is to maintain the accuracy of the tracking. Since there are 150 sheep, the trackers they purchase are for follower sheep, and the price for follower sheep is close to what they want. They can decide how many leaders they want and the more leaders, the more accurate they can view.

Reference

[1] Encyclopædia Britannica, inc. (n.d.). Mthatha. Encyclopædia Britannica. Retrieved April 17, 2022, from https://www.britannica.com/place/Mthatha

[2] An introduction to pet. Fact Sheet - An Introduction to PET (polyethylene terephthalate) | PETRA: Information on the Use, Benefits & Safety of PET Plastic. (n.d.). Retrieved April 17, 2022, from http://www.petresin.org/news_introtoPET.asp

[3] How much does an electric fence cost? CostHelper. (n.d.). Retrieved April 17, 2022, from https://home.costhelper.com/electric-fences.html

[4] The prevalence of lameness in the assessment of Transylvanian dairy herds by locomotion score and according to the Farmers' estimates. Directory Indexing of International Research Journals. (n.d.). Retrieved April 17, 2022, from https://www.citefactor.org/article/index/47309/pdf/

[5] Radiobjella Inkl batteri. Telespor. (n.d.). Retrieved April 17, 2022, from https://nettbutikk.telespor.no/products/radiobjella-inkl-batteri

[6] Location Data Accuracy - MMA. (n.d.). Retrieved April 17, 2022, from https://www.mmaglobal.com/files/documents/location-data-accuracy-v3.pdf

[7] GPS accuracy. GPS.gov: GPS Accuracy. (n.d.). Retrieved April 17, 2022, from https://www.gps.gov/systems/gps/performance/accuracy/

[8] Automated critical test result notification system: Architecture, design, and assessment of provider satisfaction : American Journal of roentgenology : Vol. 203, no. 5 (AJR). American Journal of Roentgenology. (n.d.). Retrieved April 17, 2022, from https://www.ajronline.org/doi/10.2214/AJR.14.13063

[9] Additional informationFundingThis work was supported by Intra-ACP Mobility Scheme: [Grant Number STRE1101630]. (n.d.). Determinants of profit efficiency among smallholder sheep farmers in South Africa. Taylor & Francis. Retrieved April 17, 2022, from https://www.tandfonline.com/doi/full/10.1080/20421338.2021.1879510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

[10] Developing alternatives to protect ... - escholarship.org. (n.d.). Retrieved April 17, 2022, from https://escholarship.org/content/qt58r1g4wj/qt58r1g4wj_noSplash_c05614f4da5bcb8ba3ab41e0a5266bc8.pdf?t=qf25mm

[11] FAA human factors (ang-E25) 2005-human factors guidance for the use of handheld computing devices. (n.d.). Retrieved April 17, 2022, from https://hf.tc.faa.gov/publications/2005-human-factors-guidance-for-the-use-of-handheld/

[12] Wikimedia Foundation. (2022, March 14). Mthatha. Wikipedia. Retrieved April 17, 2022, from https://en.wikipedia.org/wiki/Mthatha

[13] Goal 12: Responsible consumption and production. UNDP. (n.d.). Retrieved April 17, 2022, from https://www.my.undp.org/content/malaysia/en/home/sustainable-development-goals/goal-12-responsible-consumption-and-production.html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

[14] Katwala, A. (2018, August 5). The spiralling environmental cost of our lithium battery addiction. WIRED UK. Retrieved April 17, 2022, from https://www.wired.co.uk/article/lithium-batteries-environment-impact#:~:text=According%20to%20a%20report%20by,livestock%2C%20and%20for%20crop%20irrigation.

[15] Blog. Concox. (n.d.). Retrieved April 17, 2022, from https://www.iconcox.com/blog/how-long-does-the-gps-tracker-last.html

[16] Waterproof testing. Applied Technical Services. (2022, April 8). Retrieved April 17, 2022, from https://atslab.com/environmental-testing/waterproof-testing/

[17] Dropped objects testing (ANSI/ISEA 121). Element. (n.d.). Retrieved April 17, 2022, from https://www.element.com/product-qualification-testing-services/dropped-objects-testing

[18] Security, B. (n.d.). How to choose a GPS tracker. How to Choose a GPS Tracker. Retrieved April 17, 2022, from https://www.brickhousesecurity.com/gps-trackers/device-guide/

[19] MTN 3G / 4G / 5G in Mthatha coverage map, South Africa. MTN 3G / 4G / 5G coverage in Mthatha, South Africa - nPerf.com. (n.d.). Retrieved April 17, 2022, from https://www.nperf.com/en/map/ZA/946058.Mthatha/9863.MTN/signal/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

[20] Wikimedia Foundation. (2022, March 21). Sheep. Wikipedia. Retrieved April 17, 2022, from https://en.wikipedia.org/wiki/Sheep

[21] An introduction to pet. Fact Sheet - An Introduction to PET (polyethylene terephthalate) | PETRA: Information on the Use, Benefits & Safety of PET Plastic. (n.d.). Retrieved April 17, 2022, from http://www.petresin.org/news_introtoPET.asp

[22] Shock absorbing material. Sorbothane. (n.d.). Retrieved April 17, 2022, from https://www.sorbothane.com/shock-absorbing-material.aspx#:~:text=Sorbothane%20is%20the%20best%20solution,%2C%20neoprene%2C%20silicone%2C%20etc.

[23] An introduction to pet. Fact Sheet - An Introduction to PET (polyethylene terephthalate) | PETRA: Information on the Use, Benefits & Safety of PET Plastic. (n.d.). Retrieved April 17, 2022, from http://www.petresin.org/news_introtoPET.asp

[24] 9.08C$ 15% off: Leonardo R3 microcontroller Atmega32u4 Development Board with USB cable compatible for Arduino DIY starter kit: Integrated Circuits: - aliexpress. aliexpress.com. (n.d.). Retrieved April 17, 2022, from https://www.aliexpress.com/item/32893459152.html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

[25] 0.5US $ 12% off: NRF24L01+ 2.4G Wireless Data Transmission Module 2.4ghz NRF24L01 upgrade version NRF24L01+PA+LNA 1000 meters for Arduino - integrated circuits - aliexpress. aliexpress.com. (n.d.). Retrieved April 17, 2022, from https://www.aliexpress.com/item/1005002975667834.html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

[26] 0.33US $ 5% off: Smallest SIM800L GPRS GSM module Microsim Card Core Board quad-band TTL serial port - integrated circuits - aliexpress. aliexpress.com. (n.d.). Retrieved April 17, 2022, from https://www.aliexpress.com/item/32283531730.html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

[27] Energizer Max 9V, 1 pack: Walmart Canada. Walmart.ca. (n.d.). Retrieved April 17, 2022, from https://www.walmart.ca/en/ip/energizer-max-9v-1-pack/6000016945328

[28] Jumper wires 6" m/F pack of 20 - robotshop. (n.d.). Retrieved April 17, 2022, from https://www.robotshop.com/ca/en/jumper-wires-6-m-f-pack-of-20.html

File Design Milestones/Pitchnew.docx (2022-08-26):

Design Pitch for Sheep_Link - a Cluster-based GPS GSM Sheep Tracking System

Arielle Zhang, Tabitha Kim, Edwin Ma, Ethan Fong, Emre Cagin

University of Toronto

April 2022

# Executive Summary

In Mthatha, South Africa, many farmers face problems with missing sheep. It is tedious work to look for the missing sheep as neither the shepherds nor the farmers have cars and information on where the sheep are. Therefore, they are looking for a cost-effective solution to make finding missing sheep easier. Our team’s values are sustainability, functionality, and accessibility. This helped to develop our scope, which is to make a reliable sheep tracking system that is accessible to everyone in the community and prevents sheep from wandering off or mixing with other flocks. Stakeholder analysis gives us the two prioritized objectives: cost efficiency and functionality to track the sheep. The prioritization of these two values scoped out alternatives such as fencing and existing tracking systems. However, fencing lacks the functionality to track sheep and pure GPS trackers have an excessive cost that cannot be afforded by the stakeholders. In the end, we decided to use Global System for Mobile (GSM) and Global Positioning System (GPS) to track the sheep with a clustering system which satisfies both of our prioritized objectives. GSM allows for the transmission of data through a 2G cellular network, which was chosen since the infrastructure exists to support this system in Rosedale. We divided the flock into small groups, called clusters, with each cluster having a leader sheep with a GPS tracker to locate the cluster. Each leader sheep pings the followers within the cluster based on the Received Signal Strength Indication (RSSI), and the followers reply with their ID which is unique for each sheep using the wireless transceivers. After getting each follower sheep ID, every leader sheep sends the information to the database using the GSM network. A clustering algorithm is used to detect missing sheep, and if there are any, those sheep will be displayed in the User Interface (UI) with their ID, the most recent location, and missing time. The customized color and engraved sheep ID on the tracker allow the stakeholders to easily identify and differentiate their sheep when looking for them. Our design allows for a delicate balance between cost efficiency and functionality by reducing the GPS modules needed, assuming that most of the leader sheep will be evenly distributed among the flock. Our sustainability demand is based on fulfilling the United Nations Sustainable Development Goal 12 (UN SDG12) which includes responsible consumption and production. Thus, the choice material of the tracker is PET which is a type of 100% recyclable polymer and can satisfy the demand for sustainability and protection of electronic units inside. In addition, we selected rechargeable batteries to minimize the cost and pollution.

Table of Contents

1. Introduction
2. Backgrounds
  2.1. Stakeholders
  2.2. Service Environment
  2.3. Scoping
  2.4. Team Values
  2.5. Reference Designs
  2.6. Requirements Model
3. Design Process and Key Design Decisions
  3.1. Conceptual Design
  3.2. Prototype
  3.3. Influence of Reference Designs on Process
  3.4. Verification
  3.5. Validation Chart
  3.6. GSU Reflection
4. Discussion of the Final Outcome
  4.1. Assumptions and Limitations
  4.2. Progress of the Prototype
  4.3. Team Process
5. Conclusion
  5.1. Current Prototype
  5.2. Future Steps
6. References

Appendix I. Testing results

Appendix II. Team

Appendix III. Bill of Materials

# 1. Introduction

Small sheep owners in the small town of Rosedale, Mthatha are struggling with retaining their sheep. As livestock farming plays a major role in their economy, losing sheep is critical [1]. There are several situations where a sheep could get lost; they could simply wander off, get mixed up with different owners’ sheep, or could not be taken care of due to the absence of shepherds. Therefore, we and the stakeholders are seeking a solution that has reliable functionalities to track the location of lost sheep such that the loss can be prevented. Here, as the stakeholders include sheep owners and shepherds, the solution must be accessible in terms of cost (one of the most emphasized requirements by the stakeholder), portability, and ease of learning. Furthermore, as our team values sustainability as required by UN SDG 12, a design with a responsible consumption and production process that is durable is also preferred.


Figure 1 Sheep_Link conceptual design flowchart

Our solution is a system we have decided to call Sheep_Link. Sheep_Link is an accessible and reliable GPS GSM sheep tracking system that prevents sheep loss. The system includes the GPS GSM tracker collar, backend database and frontend UI. To balance between the two most highlighted high-level requirements by the stakeholders: cost efficiency and functionality of location tracking, we decided to use cluster tracking method. This allows the reduction of GPS modules needed by only tracking the location of clusters of sheep. There are two types of sheep trackers for each sheep to support this, a leader tracker and follower tracker. Each tracker stores a unique sheep ID: the leader’s ID starts with an “F”, and the follower’s ID starts with an “L”. Both types have wireless transceivers but only leader sheep has GPS GSM module to gather the location and transmit information to the backend database. When updating, leaders ping nearest followers based on the RSSI, and followers respond by sending their IDs to the leader. Following that, the leader sends all the IDs in the cluster and its own current GPS location to the backend database. The cluster size is customizable depending how many leader trackers the user wants, having smaller cluster size provides more accurate location tracking with a trade-off to be a higher cost because the GPS module is the expensive part of the tracker. A backend clustering algorithm will send missing sheep alerts including missing sheep location and missing time through the UI whenever a missing sheep is detected. Also, keeping the UNSDG 12 in mind, we designed the physical tracker to be using recyclable polymer [2], and rechargeable batteries.

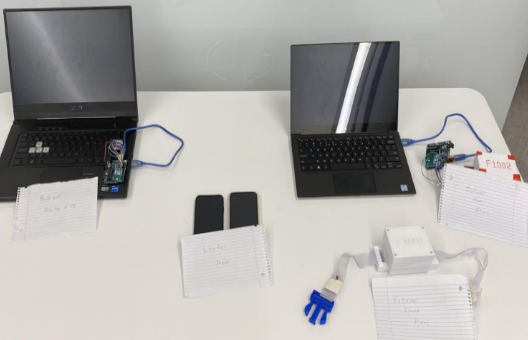
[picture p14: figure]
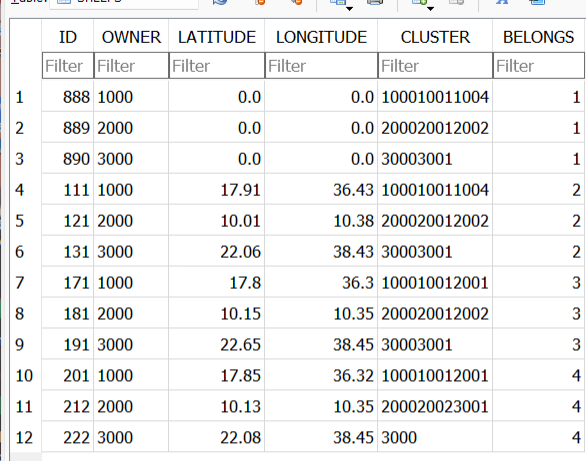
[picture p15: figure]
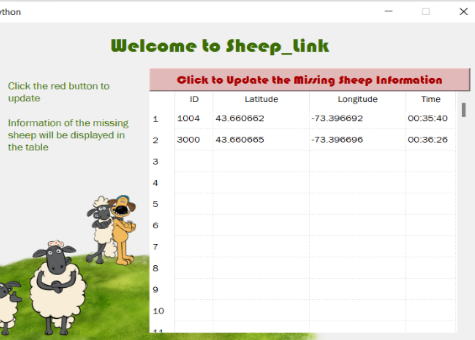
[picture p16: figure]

Figure 2 Final prototype of the trackers, the backend database and the UI

To verify this design, we prototyped two fully functional follower trackers (Figure 2) with the Bluefruit LE UART Friend module and Arduino UNO R3 microcontroller. The first follower collar has an ID of F1001 is powered by a 9V battery, and it has a complete case concealing the electronics with an adjustable belt strap. The second follower has an ID of F1002 is powered by the laptop but also has a case to store the electronics. We decided to use the phone as a proxy for the leader collar because the Bluefruit module app supports multiple UART modes, allowing us to ping several follower trackers at the same time, and it has the GPS location of the phone, making it the best representation of our concept. Once pinged by the leader, followers will send their IDs to the phone through the UART communication protocol over Bluetooth. This represents the GSM transmission module by manually sending the follower IDs and the GPS location to the backend database. The backend database and UI (Figure 2) was developed using SQLite and python and is fully functional. The algorithm can detect both missing leaders and followers. The UI displays all the essential information for the shepherds including the missing location and missing time of the missing sheep. The UI is also designed for better accessibility as it is available in both English and Xhosa and requires no technical training. The final prototype for one collar costs using MyFab facility prices amount to a total of $49.65 CAD (Appendix II. BOM)

# 2. Background

## 2.1 Stakeholders

The sheep owners in the rural town of Rosedale, Mthatha are the primary stakeholders. The stakeholders wish to have an economical solution that reduces their losses in owning a flock of sheep by reliably tracking the lost sheep. Currently, they need to search a vicinity usually 1-2 km away or nearby homesteads up to 5 km away without cars to find the missing sheep. To maximize benefits for most sheep owners, accessibility is highly valued. Considering the technical abilities of the shepherds, implementing the solution should be done in a way that is easy for the shepherds to handle. In this proposal, we prioritize the needs and values of our primary stakeholders; however, secondary stakeholders such as shepherds and sheep are also important. The shepherds are underpaid and are often given a high workload; thus, the owners have a precarious relationship with the shepherds. Reducing the shepherd’s workload by introducing high functioning designs that can motivate them to work to minimize the chances of sheep getting lost is a priority. For the sheep, the solution should not reduce the economic value of the sheep both directly and indirectly, thus the solution should not harm the sheep.

## 2.2 Service Environment

The opportunity is set in the town of Mthatha in Eastern South Africa. Sheep farming is popular in this region, and many sheep owners share communal grazing areas. The grazing area is a (3) mixture of rural village land and hilly plains as seen by images provided by the stakeholder. The climate of the region is moderately cold, with a yearly high of around 27 degrees, so for most of the year, the sheep will be grazing in the cold. The design should serve the stakeholder’s need to find the lost sheep and keep the cost minimized. With the local service environment described, the design functions should support successful tracking and finding sheep when they are lost while being easy and convenient for local owners and shepherds to operate. The durability and safety of the product should be suitable to local climate and environmental factors, which require features such as waterproofing and dustproofing.

## 2.3 Scoping

With internet and mobile network coverage, the assistance of shepherds, and the limitations on budget, we scoped to develop a reliable sheep tracking system that is accessible to every community member in Rosedale, which can prevent sheep from wandering off or mixing up with other sheep. The focus of the design will be its reliability to prevent the sheep from missing and its feasibility of being integrated into the daily lives of the shepherd. The product must be sustainable to fulfill UN SDG12 which concerns responsible consumption and production.

## 2.4 Team Values

Our teams had three main values that will be incorporated into the requirements model: functionality, accessibility and sustainability. Functionality is one of the main priorities of the design since the shepherds are looking for a design that will address the issue of wandering sheep. This will include tracking capabilities and a system that is accurate and accounts for all possible instances of sheep wandering off. Additionally, we incorporated empathy into the design in the form of accessibility. We focus on making the product accessible to everyone in the community by keeping it affordable and easy to learn. Lastly, in keeping with the goal 12 of the UN SDG, sustainable consumption and production in mind, we aim to make the design durable to improve resource usage efficiency. The extended lifetime of the product reduces the cost for the stakeholders and is identified as responsible consumption promotion.

## 2.5 Reference Designs

Fencing is a popular solution for problems with animals wandering off. Fencing an area is simple and effective to prevent animals from leaving. However, for our stakeholders, it is not a valid solution. Because many shepherds in Rosedale share a communal grazing area, the coordination of fencing would be complicated. Also, the price is estimated to be 7500 – 15000 USD (9500-19000 CAD) for the area of grazing land the shepherds have, which is very expensive when compared to the price requirements provided later [3]. Another option that has been used to find sheep is GPS tracking. This has been used for sheep tracking in countries such as Norway [4]. The Telesport system is the current “market-leading" solution and makes use of a GPS to locate every sheep in real-time. However, this is also costly at 290 CAD per sheep, with no flexibility since each sheep’s collar will make use of GPS technology [5].

## 2.6 Requirements Model

The requirements model was developed to fulfil the needs of our stakeholders by successfully preventing sheep loss and ensuring that the design would be feasible to integrate. We incorporated our value proposition by deriving the high-level objectives from the three values. From each high-level objective, we developed detailed objectives to be our specific testing protocols. We will validate the design by either physically testing if possible or otherwise theoretically predicting the outcome against each proposed requirement to assess to what extent our design delivers the values to the stakeholders.

Functionality: Location Tracking

The primary functions of the design should include a lost sheep notification system and finding system to fully address the missing sheep issue. The first functionality requirement is that it must track the location of the sheep.

Table 2 Criteria, metrics, and constraints for location tracking

Criteria: tracking range
Farther is better (m) | Must ≥ 2000 m. Should ≥ 5000 m

Criteria: location accuracy: closeness of a measured location to the real location of the device at the time of measurement [6]
The closer is better (m). GPS level accuracy is within 4.9m[7]. | Must not exceed 20m to provide an accurate location of the sheep

Functionality: Reliability

Reliability requirements ensures handling the different cases of the sheep wandering off, and that the shepherds can be notified within time to take preventative action.

Table 3 Criteria, metrics, and constraints for the reliability

Criteria: reliability of the notification communication

Metric: Percentage error of false alert (%); lower is better

Constraint: Must not be interrupted and interfered with when transmitting messages.

Constraint: Should allow notification documentation, and record all the history notifications [8]

Accessibility: Affordability

The requirement that was emphasized the most by the primary stakeholders was cost-efficiency. The stakeholder provided an ideal cost of 150 * 12 CAD = 1800 CAD for the final product. However, recognizing the challenge to implement solutions with high functionality to track the sheep’s location accurately and reliably, we justified cost constraint of the final design to be less than 3400 CAD because the average purchase price of the sheep in South Africa is approximately R1,300 and the average sheep output of small livestock owners is R3,000 [9]. The average profit efficiency of the sheep was estimated to be about 65.5% [9]. Therefore, the strict profit made by each sheep can be estimated to be around R2,000. On average, small livestock owners have 150 sheep, and the rates of sheep loss has an average of 8% [10]. Hence, the minimum loss would be about 12 sheep. Therefore, we set the constraints for the budget to be (the strict profit each sheep makes + the price of the sheep) * (the number of sheep that get lost) as the design should be profitable in the end. Therefore, our hard constraint is that our design must not exceed (R2,000 + R1,300) * 12 ≈ R39,600 = 3410 CAD per year.

Accessibility: Portability

As part of the design for travel and ergonomics, the solution needs to be able to move around freely to track the sheep at different locations. Portability requirements for handheld devices were taken from the 2005 US human factors guide for the design of handheld devices. Two of the main concerns for devices are the weight and dimensions of the device. Note that the dimensions of the device are specified as the stow-away size; some devices may unfold but must stow away to under the size constraint.

Table 3 Criteria, metrics, and constraints for portability

Criteria: Device needs to be easy to move around, and shepherds must be able to use the device over the range of the grazing area (~5km through hilly terrain and villages).
A lighter device is preferred (weight in pounds) | Widgets should be under 5.1 pounds if handheld. [11]
A smaller stowaway volume is preferred (size of dimensions in mm) | Widget should stow away to under 100x125x255mm in size [11].

Accessibility: Ease of Learning

The product should have the option to display information in the local language Xhosa [12]. Since the solution will be implemented with local shepherds, there also needs to be education in teaching them how to use the design solution. The less time it takes for the shepherds to learn how to use the design the better. This will depend on the quality of the user interface and should contain features such as one-click information finding and intuitive graphics.

Sustainability: UNSDG 12 Responsible consumption and production

Responsible consumption and production objectives relate to the materials used for the physical collar [13]. The goal is to use materials that have the smallest carbon footprint and can be recycled if the product were to be taken apart. An additional consideration is the impact of the battery, using rechargeable batteries instead of lithium batteries reduced soil and air contamination [14].

Sustainability: Durability

High durability reduces product costs for the stakeholders by reducing the amount of maintenance needed. Besides the cost, durability also encourages responsible production by increasing resource efficiency. Considering the grazing area is close to water sources, the product needs to be waterproof, dustproof and drop proof.

Table 4 Criteria, metrics, and constraints for durability

Criteria: Device needs to work for an extended period without malfunctioning

Metric: The lifetime of design [15]

Constraint: Must pass waterproof and dustproof test from IP5 to IP6 [16]

Constraint: Must pass drop test for ANSI/ISEA 121-2018 [17]

Constraint: Must work for at least two weeks without charging [18]

# 3. Design Process and Key Design Decisions

In our project management plan, the team is divided into three divisions: hardware of the tracker, physical design of the collar, and software, which includes the backend database and front-end UI. Three engineers from our team are assigned to be the lead of each division, and deadlines for design milestones are set to check the progress of all three divisions and merge the work.

## 3.1 Conceptual Design Features

1. Using GPS to track the sheep's location: as required by the stakeholder, the design needs to track the exact location of the missing sheep. We interpreted this requirement to be minimizing the effort spent when searching for missing sheep. In our design, we use GPS tracking to monitor the sheep’s location and notify the shepherds once the sheep leaves the cluster. This way the shepherds can efficiently target the wandering sheep and get it back immediately, reducing the workload. Thus, we believe it is the best solution that satisfies the stakeholder’s needs.

2. Using clustering methods to reduce the cost: the tradeoff for using expensive GPS trackers is the excessive cost. The stakeholders not only value functionality, but also value cost efficiency. However, we recognized the conflict in satisfying both. The clustering method leaves the choice of whether to be cheaper but have a larger location uncertainty or to have a smaller location uncertainty but be more expensive to the stakeholder.

3. Using GSM to transmit information: from the context provided by the stakeholders, the town of Rosedale has mobile phone coverage. Furthermore, research has shown that Mthatha has full 2G GSM coverage provided by Vodacom, Telkom, and MTN [19]. Accessing the GSM network is cheaper than Wi-Fi, 3G, 4G, and 5G networks and therefore reduces the cost. Here, it should be noted that as great as GSM is for increasing affordability, this pricing is in exchange for the speed of the connection. Nevertheless, as 2G network is still integrated into our daily lives, the connection speed is sufficient for this application.

4. Accessibility of the UI: To make the product easy to use for the shepherds and sheep owners, we designed the UI to have both English and Xhosa versions. Also, the one-click-to-update feature is very user-friendly, requiring zero technical training.

## 3.2 Prototype

In our PM plan, we separately prototyped and tested our hardware and software subsystems, due to resource limitations, we did not prototype the GSM module and instead used Bluetooth to represent this feature. To demonstrate the full functionality of the conceptual design, we prototyped both types of the trackers, the physical collar, and the database with the UI. During our prototyping process, we identified that RSSI’s inaccuracy in predicting the distance is the biggest problem to our design because our key concept, clustering method, relies on calculating the distance using RSSI. We would need to do more research to improve this situation. Except for this main problem, all other parts of the subsystem functioned as expected from our conceptual design. Our prototype is comprised of the following parts:

1. We prototyped one battery powered follower tracker with the hardware concealed in the physical collar to demonstrate the design concepts. The second follower prototype is only powered by the laptop to save batteries (practicing UNSDG 12). We decided to prototype two followers because we need to test the clustering functionality based on the RSSI strength.

2. We decided to use Bluefruit Connect phone app as the leader sheep because the app has a multiple UART mode, accurately representing the idea of leader sheep calling multiple follower sheep at once. Furthermore, the app allows us to acquire the GPS location of the phone, representing the GPS module to be implemented in the product. The leader communicates with the backend using Bluetooth, which is a proxy of the GSM transmission because MyFab does not have a GSM module. Then we need to manually send the information (GPS and the collected follower IDs) to the backend.

3. We fully prototyped the backend database using SQLite and Python and prototyped the UI using PyQt5. We chose to use database because compared to txt files and excel, SQL database is the most efficient way to store and handle large number of update messages because we need to use python to extract write information into the database to detect missing sheep. We chose to use PyQt5 to write the UI because it is intuitive and widely used.

## 3.3 Influence of Reference Designs on Process

The most relevant reference design that influenced our thinking as a group was the Telespor system from Norway mentioned earlier in the reference design section. The main drawbacks of the solution that made it unsuitable for our opportunity were that it is costly and would be hard to integrate into the shepherd’s operation due to language constraints (the Telespor system is not offered in the local language Xhosa). Our design addresses these two issues by offering flexibility on how many GPS modules to include, lowering the price point. Additionally, we have designed our UI to be usable in many languages including Xhosa, and features such as one-click updates ensure that the design is accessible to the shepherds. However, our design is not as developed as the telespor system, and further improvements on battery life and the design of the leader sheep’s collar may increase the price of the design.

## 3.4 Verification

To ensure the high-fidelity prototype is functional, reliable and error-free, we tested each subsystem with repeated trials. Note that since our leader collars were proxied using mobile phones, this does not allow the collected information to be automatically sent to the backend, thus each component (hardware, software and physical collar) was verified individually.

Electronic Subsystem and Hardware

To verify the electronic pinging system, we tested:

1. Whether RSSI range can be used for clustering.

2. Pinging the sheep and how it responds with the identification number.

3. The feasibility of powering the system and running the circuitry with the 9V battery.

Testing of the RSSI was done by graphing the RSSI against distance. The RSSI strength works for clustering but becomes unreliable at longer distances since the signal strength falls off exponentially (Figure 4). Then we verified different cases of pinging followers. We used the Bluefruit app to test if we can ping both sheep, and each individual sheep (simulating the case where the other sheep is out of range). We successfully pinged both followers using the multiple UART function of the app, proving that in our final design we can ping all nearby sheep with a single message.

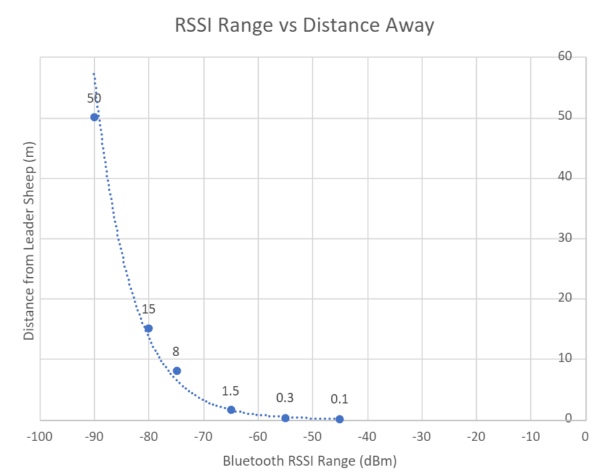
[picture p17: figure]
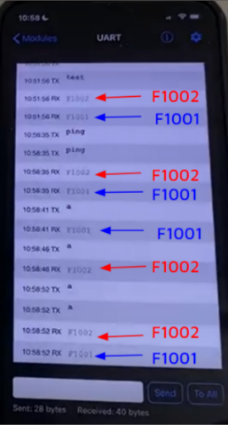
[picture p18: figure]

Figure 3 RSSI versus distance away plot and the cluster follower sheep response based on RSSI

Lastly, the Arduino was sufficiently powered by the 9V battery and supplied constant power throughout our 1 hour testing sessions, verifying that the battery life of the prototype was adequate and can be improved through further research and development.

Physical collar

The base of the tracker fits the Arduino (Figure 6), and the Bluefruit and the battery were physically taped onto the second layer, preventing the electronics from moving inside the case even when dropping to the ground from a 1-meter height (the standing height of a sheep).

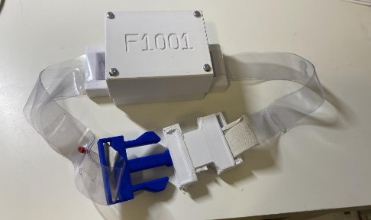
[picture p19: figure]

Figure 4 Dimension graph in mm of the tracker and final printed design

The hardware is waterproof such that the tracker inside was safe from any damage when proxy waterproofing in the form of rubber bands was added. This was tested by putting tissues inside the cover and sinking it underwater for 2 hours, following the test for waterproof and dustproof levels IP5 and IP6. The engraved sheep ID in 3D printing is clear and easy to see.

Backend Database and Clustering Algorithm

The backend algorithm passed all testing cases. We created a three-leader sheep flock for this testing, therefore there will be three data entries into the database for each update.

Table 5 Testing cases for the backend database and clustering algorithm

Leader ID | Follower IDs | Case 0 initializing the database Algorithm output: no missing sheep.
1000 | 1001, 1002, 1003, 1004, 1005
2000 | 2001, 2002, 2003, 2004, 2005
3000 | 3001, 3002
1000 | 1001, 2001, 1002, 1003, 1005 | Case 1: 2001 and 1004 changed clusters Algorithm output: no missing sheep.
2000 | 2002, 2003, 2004, 2005
3000 | 3001, 3002, 1004
1000 | 1001, 2001, 1002, 1003, 1005 | Case 2: missing follower sheep when it leaves the flock Algorithm output: missing sheep 1004, the most recent GPS location of the cluster (sheep 3000’s location), and the missing time.
2000 | 2002, 2003, 2004, 2005
3000 | 3001, 3002
1000 | 1001, 1002, 1003, 1004, 1005 | Case 3: missing leader sheep when it has an empty cluster Algorithm output: missing sheep 3000, the most recent GPS location of 3000, and the missing time.
2000 | 2001, 2002, 2003, 2004, 2005, 3001, 3002
3000

User Interface

The UI displays missing sheep information in local languages with a clickable button allowing the user to manually refresh the page. One shortcoming of the database is that it does not automatically refresh. The user interface was done using the PyQt5 library.

## 3.5 Validation Chart

To ensure the high-fidelity prototype is delivering the values we would provide to the stakeholders, we assessed and/or tested the prototype against each detailed objective. We noted that all the requirements identified earlier were met.

Functionality

Criteria: tracking range

GPS has global coverage, allowing sheep to be tracked anywhere in the world.

Criteria: location accuracy: closeness of a measured location to the real location of the device at the time of measurement [6]

The leader trackers have GPS level accuracy which is within 1m < 20m [7].

Depending on the number of leader trackers the follower tracker location uncertainty is:

Max location uncertainty = 14.5m < 20m (see Appendix I. Section 1. for calculations)

Assumption: sheep activity range is 2m [20], worst-case scenario is all sheep standing in a row.

Criteria: reliability of the notification communication

Since the sheep are clusters based on the RSSI, and RSSI sometimes is not a perfect estimation of distance. Our testing result has a 20% failure rate (see Appendix I. Section 2.) when the follower tracker’s distance from the leader sheep is further than the calculated cluster radius, but it still did not disconnect.

Bluetooth wireless transceiver and GSM both have stable, reliable signal.

The backend database is implemented in SQL, allowing to store large number of updates.

Accessibility

Criteria: low cost

Depending on the number of leader trackers the follower tracker location uncertainty is:

Min cost with 50% leaders: 75*12.93 CAD + 75*17.28 CAD = 2265.75 CAD < 3410 CAD

(See the BOM for each leader tracker and follower tracker is in Appendix II.)

Criteria: Device needs to be easy to move around, and shepherds must be able to use the device over the range of the grazing area (~5km through hilly terrain and villages).

Tracker is 0.22 pounds < 5.1 pounds. (See Appendix I. Section 3.)

Tracker is 85x70x45mm < 100x125x255mm in size. (See Appendix I. Section 4.)

Criteria: Ease of Learning

The UI has both English version and Xhosa version and is easy to use with no prior experience and/or training needed.

Sustainability

Criteria: UN SDG responsible consumption and production

The design can be fabricated using recyclable polymer PET [21] and rechargeable batteries.

Criteria: Device needs to work for an extended period without malfunctioning

The design can be designed to pass waterproof and dustproof test from IP5 to IP6 [8].

The design can be designed to pass the drop test for ANSI/ISEA 121-2018 [21] by soldering all the electronics onto the surfaces and using shock absorption polymers [22].

The design can use rechargeable batteries that sustain two weeks without charging [10].

## 3.6 GSU Reflection

We incorporated the GSU student’s suggestion to include more stakeholders, such as governments, by making our design more sustainable by using green materials and rechargeable batteries to comply with local government environmental regulations. The material that we can use is PET which is a representative of recyclable polymer. PET is a clear, strong, and lightweight plastic [23] that can be used as the material for the case and can be able to pass the drop test and protect the inner modules. PET is fully recyclable, and it is the most recycled plastic in the U.S and worldwide [23], so this material can support us to pass the requirement of UN SDG12. The GSU student also brought up the issue of any alternatives in case of technical difficulties. We recognized that it is risky to assume fully reliable 2G GSM coverage in Rosedale. Research shows that near the water dam, Rosedale is not fully covered by stable 2G nor 3G/4G networks. However, further research tells us that in the future we can implement a hopping algorithm [29] to solve this problem if at least one sheep is in the 2G GSM coverage.

# 4. Discussion of the Final Outcome

With local context in Rosedale, Mthatha, our proposed design Sheep Link is a valid solution that prevents sheep from wandering by tracking the GPS location and notifying the shepherds when a sheep wanders off. Such preventive methods significantly reduce the efforts the shepherds and the sheep owners need to spend when searching for missed sheep. Sheep_Link delivers functionality, accessibility, and sustainability to the stakeholders by satisfying the corresponding detailed requirements. The requirements for functionality are location tracking and reliability, the requirements for accessibility are affordability, portability, and ease of learning, and lastly, the requirements for sustainability are durability and UNSDG12. Sheep_Link provides reliable tracking of the wandering sheep’s GPS location, integrating the feature of the engraved sheep IDs on the physical collar and their customizable colors, shepherds/owners can easily find or differentiate their lost sheep. GSM signals are cheap but stable methods making our design suitable for the objective of cost-efficiency. Furthermore, to balance the functionality and cost-efficiency, the number of the leaders can be customized to increase or decrease the number of GPS modules, allowing stakeholders to decide to what extent they want to sacrifice location accuracy over cost or vice versa. The design is easy to be used by local people since it is in the local language Xhosa. The design of the case is durable in terms of waterproof and dustproof. Rechargeable batteries and green materials will be used for the product to fulfill the UNSDG 12. To summarize, besides the reliable functionality in preventing missing sheep, our design is also highly compatible with the local context financially, culturally, and environmentally, making our design a valid solution for the stakeholders.

## 4.1 Assumptions and Limitations

Assumptions were made for the conceptual design, which could lead to limitations in the design. The main limitations are outlined here. Firstly, the leader sheep distribution when calculating the cluster range was assumed to have a maximum of 2 metres. This range can be expanded by using longer range wireless communication hardware. Another assumption we made was that there exists adequate 2G network coverage over the service area. Although in our verification section, we found that the infrastructure for GSM exists, in reality the coverage may not cover the entire area sufficiently. A possible solution mentioned in the GSU reflection section is to implement what is known as a hopping algorithm. For the software component, we assumed all the stakeholders have access to an electronic device capable of running SQLite databases and has a PyQt5 library for the UI. This can be implemented on mobile phones, which the stakeholders have access to. Lastly, the shepherds have to depart to search the sheep immediately when the alert is received, which we have identified as a major limitation of the design.

## 4.2 Progress of the Prototype

The main feature of the conceptual design, the clustering method, is feasible for a group of second year EngSci students to prototype with limited resources, providing us with confidence that the final design would be feasible to do by the same team with more choices of the modules. The follower tracker, the physical collar, and the software are fully prototyped; however, the leader tracker and the GSM transmission features are only proxied by using the Bluefruit phone app manually sending the messages to the followers and to the backend because we do not have enough technical capabilities to design the more complicated leader tracker and MyFab does not have the modules we need. The physical collar prototype represents most of the important features of our final design: three layers to hold the electronics in place, an adjustable strap, waterproof/dustproof rubber band, and engraved sheep IDs. However, the dimension of the case should be smaller in the final design when we use different modules and minimize the space needed to fit the components. Green materials instead of 3D printing materials can be used in real design. The backend database is created, and the algorithm was able to report missing sheep correctly in all scenarios stakeholders might encounter. The software component is ready to work under real-life conditions. One improvement of the UI is that it needs to be improved using a better language instead of PyQt5 in Python for the real design because it does not allow automatic update and display of the missing sheep information. It can also be made into a mobile app, affording more options for the shepherds to access the software.

## 4.3 Team Process

Our team cooperated in a highly efficient and highly functional manner for this project. Arielle is the project manager; she monitors the progress of the project. Tab organizes the folders and documents everything. Yiqun is responsible for the procurement and budgeting. During the prototyping phase, there are three divisions, Ethan and Arielle are electrical engineers for the hardware division, developing the circuits for the tracker. Emre is the software engineer for the software division, developing the database and the UI. Yiqun is the mechanical engineer for the collar design division, designing the physical collar. Tabitha researched the application of GSM and 2G network, which is the only part of our system that we did not prototype due to limited access to resources. We update each other weekly in our group chat, and design milestones are set to integrate and merge the works from all three divisions.

# 5. Conclusion

Our value proposition was to develop a sustainable, reliable sheep tracking system that is accessible to every community member in Rosedale, Mthatha. Our final design uses two different types of sheep collars – leader and follower - to send information to a database, where the shepherds can easily interact with the user interface to find the location of missing sheep. The prototype of this design was split into 3 components – the hardware, software, and case design. From prototyping of the hardware, we have shown the validity of using RSSI to cluster sheep, multiple UART communication to ping nearby collars and having a battery to power the collar. The database and user interface showcase the functionality of the algorithm, and the design of the software with SQL databases allows for scaling with more sheep’s collars. Finally, the physical case was tested to be durable, waterproof, and built with sustainable materials. These three aspects of the prototype combine to give our team confidence in recommending the design going forward.

## 5.1 Current Prototype

Our prototype can support the arguments by passing all the requirements that we have. For the physical collar, the design helps it to pass the waterproof and dustproof dust of the IP6 test. For the frontend and backend, we can collect data on the locations of our products and detect when sheep have wandered off through our test cases.

## 5.2 Future Steps for Prototyping

Further prototyping and testing that has been identified by the team include the creation of a leader sheep collar. Although the leader sheep collar is a crucial part of the final design, we have proxied this part of the system with two mobile phones. The downside of using mobile phones is that they contain very accurate GPS coordinates and can easily connect to many devices. Testing on the leader sheep collar would include its ability to be powered by a battery, whether it is able to seamlessly connect and disconnect with nearby devices and whether the additional hardware requirements would change the physical case structure.
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

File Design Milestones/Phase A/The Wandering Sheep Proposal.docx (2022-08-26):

Cover Page:

The Wandering Sheep Proposal (change this to a more descriptive title later)

Table of Contents:

I. Executive Summary
II. Opportunity Statement
III. Background and Design Goals
IV. Design Considerations
V. Proposed Outcomes and Deliverables
VI. Project Management Plan Summary
VII. Team
I. Executive Summary
II. Opportunity Statement:
  a. Provide a brief overview of the situation/context and the stakeholders. (Tab)

Sheep are a significant part of many community members’ lives of Rosedale, Mthatha as most of them either own sheep or serve as shepherds [agorize]. As a result, Mthatha’s economy is heavily dependent on livestock farming []. Here, there is an ongoing issue of losing sheep mainly due to them wandering off, different owners’ sheep getting mixed up, or shepherds not showing up [agorize].

When the sheep wander off, they tend to move within a 1-2 km radius where due to the high concentration of sheep, easily get lost and end up falling into ditches, getting attacked by stray dogs, and more. Moreover, the sheep getting mixed up between community members are very common as the feeding area is limited and most of them do not have cars for the occasion. Hence, the role of a shepherd is important yet the relationship between the shepherds and owners is insecure as an outcome of underpayment, resulting in frequent and unanticipated absences.

Therefore, we are looking for a cost-efficient, … (cont. once requirements are finalized) … solution to either retain the sheep, preventing them from going missing, or track the lost sheep such that the owners can easily locate them. … (relate to team value)

Add how they graze their sheep, their pains

Add their local environment/challenges to this opportunity

Maybe also add their local culture

  b. Frame the opportunity from the perspective of stakeholder needs. (Arielle)

Understanding the stakeholders

In the opportunity statement overview, the context provider requests a cost efficient, effective location tracker of the lost sheep for the farmers in the rural towns.

Primary stakeholders:

1. Sheep owners in the rural town area of Rosedale, Mathatha

Secondary stakeholders:

2. Shepherds
3. Sheep

Framing the opportunity:

The living conditions for the sheep owners in Mathatha is in poverty according to UN _____ standard [find a source], therefore, the stakeholder needs the solution to be cost effective, which is also explicitly requested and emphasized by the context provider Alex Kizito.

In the overview, the stakeholder expresses their needs of tracking the exact location of the lost sheep. However, this need can be reframed by

break down this first identify when sheep is lost, then be able to track or facilitate the sheep owners in finding the sheep. The framed technical foci in this project is on finding the sheep. Although in the context, the stakeholder explicitly required to track the exact location of the lost sheep, the latent primary stakeholder’s need is to prevent the loss sheep and/or to successfully find the sheep when they are lost. Tracking the exactness location, on a technical level may be more costly, which may conflict with the cost efficiency requirement. Therefore, balancing between the cost and functionality, we decide the reframe the opportunity to be prevent sheep loss with a cost-efficient solution. This frame provides more flexibility for our design team to experiment with different technology to maximize the level of satisfaction in meeting the stakeholder’s needs.

  c. State the team’s value proposition, which relates to the stakeholder needs.
  d. Outline design-agnostic requirements that any solution would need to fulfill (i.e., define what it means for a solution to provide value in relation to the context and stakeholder needs). (Edwin)

Teams positionality?

Values

Team’s Values:

- UN SDGs/Strategyzer
  - Sustainability/green energy/reusability
  - Where do we source the materials from?
- Design for Durability: Functionally, the solution should last long (maintenance should be easy etc.)
- Equity:
  - Ease of learning
  - Affordability
III. Background and Design Goals
  a. This section provides the reader with relevant background for your opportunity context. As you want to demonstrate how the opportunity context will frame your design goals, your team should consider the following: (Ethan)
  b. 1. Understanding broadly the stakeholders and the context – Who is affected by the opportunity context and how? Where are they situated? What is their lived experience and what factors (societal, political, etc.) affect this? What are different forms of value that meet stakeholders’ needs? (Arielle)
  c. 2. Defining the value proposition and scope – What are the limits to what you can do (and not do)? Of the potential forms of value identified, what value proposition are you focusing on and why? How does this value connect to the UN SDGs that are relevant/important to your context? (Arielle Tab Emre)
  d. 3. Describing the service environment within your scope – What is the situation in which a design that supports your value proposition must work? (Arielle)
  e. 4. Researching and analyzing how other people have generated, or attempted to generate, the value you propose to deliver in your context. What have others done to provide solutions? What reference designs are available and how well did they work? Does any engineering design literature show there are opportunities to improve upon or leverage previous approaches? (Ethan)
  f. 5. Defining design goals in the form of requirements – what are the high-level objectives that any solution must meet? How might you go about verifying and validating any design to meet your criteria? (Move our requirements to here)

The setting of this opportunity:

- relates to the African town of Mahatha, which has a size of around 140000 people

Value Proposition and scope:

- Add stuff here

Affordability:

As engineering students from diverse backgrounds that have experiences of being framed as cultural minorities, we value equity. This leads to our value of affordability as we understand the perspectives of financial minorities and therefore seek a design that is affordable to all community members, avoiding inequity due to cost.

service environment:

- Cell phone connection exists
- Mainly hills, not many obstacles, but also other farmers’ homes
- Must be usable by shepherds who likely don’t speak English (>85% of people there speak Xhosa)

Reference designs:

- Most common design for sheep farmers is electric fencing, however, the fact that they can’t implement this is likely due to the cost constraint.
- Electric fencing isn’t perfect because it needs to be maintained, and the relationship between farmers and shepherds is precarious

Requirements:

1. Cost Efficiency (Tab)
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

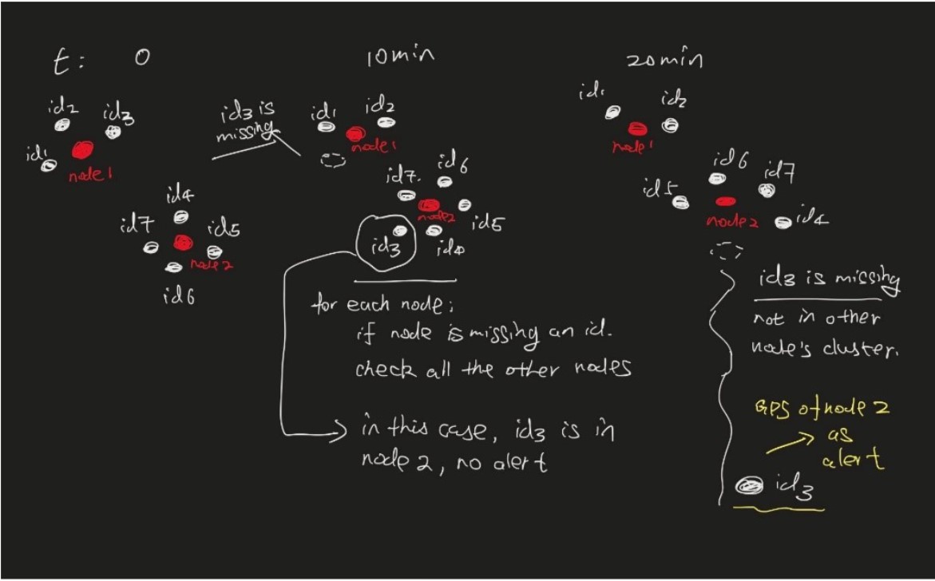
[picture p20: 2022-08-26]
Design Pitch Artefacts/Design Consideration and Prototyping Artefacts/Phase A/Sketches/Cluster Idea.jpg

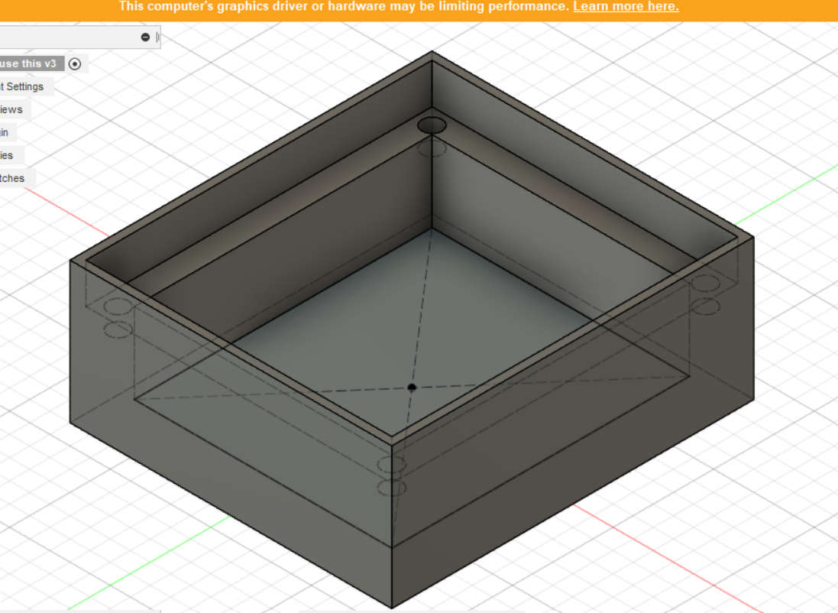
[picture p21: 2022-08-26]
Design Milestones/Prototype/Physical Collar Design/Version2_Cover(IP).png

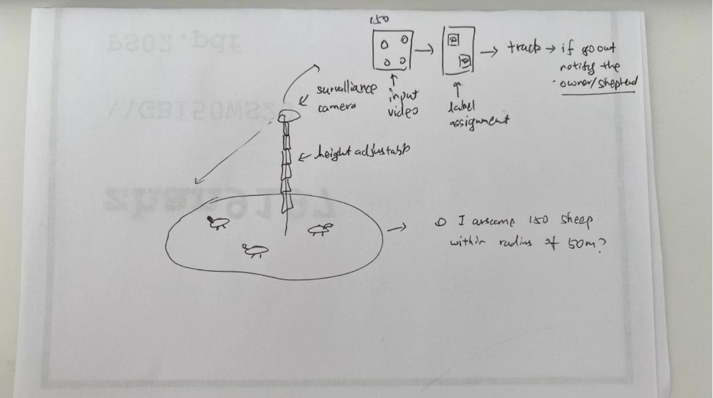
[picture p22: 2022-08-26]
Design Pitch Artefacts/Design Consideration and Prototyping Artefacts/Phase A/Sketches/image recognition resim.jpg

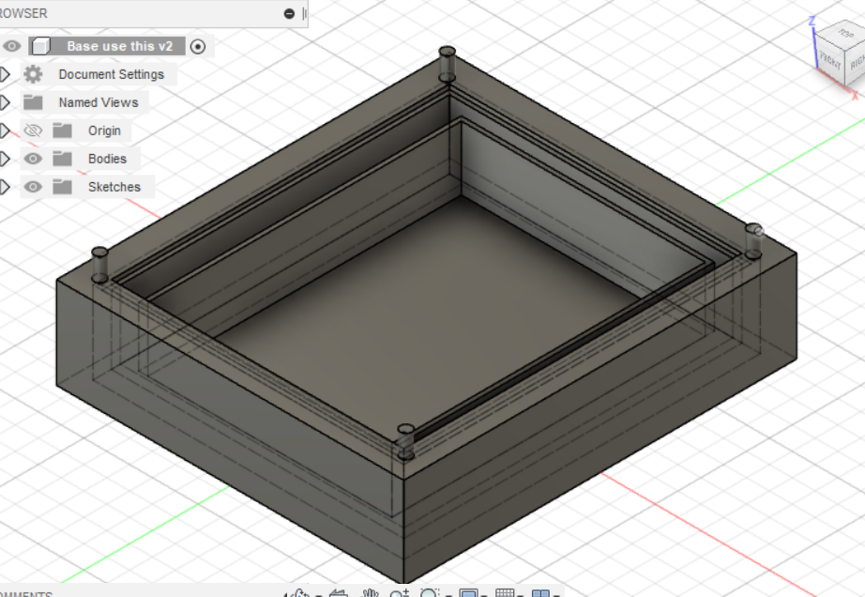
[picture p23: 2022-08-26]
Design Pitch Artefacts/Design Consideration and Prototyping Artefacts/Phase B/Physical Collar Design/Version2_Base(IP).png

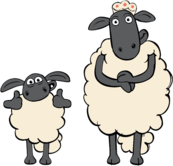
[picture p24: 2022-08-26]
Design Milestones/Prototype/Back End/Final Release Version/sheepresized.png

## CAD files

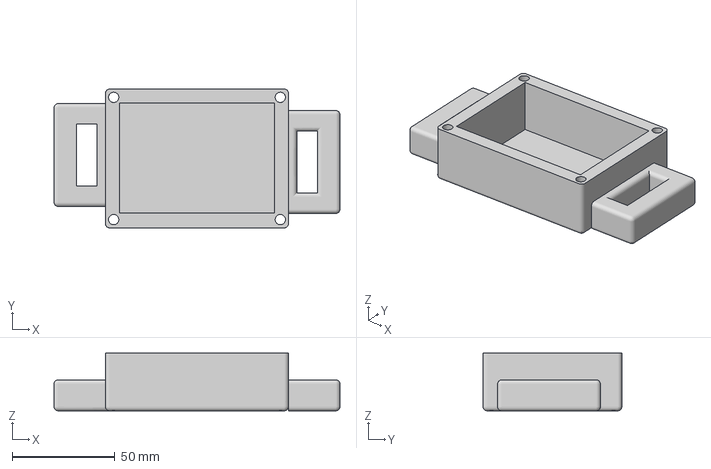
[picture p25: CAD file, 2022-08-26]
Design Milestones/Prototype/Physical Collar Design/FINALBASE.3mf
138.9 x 67.4 x 28.0 mm

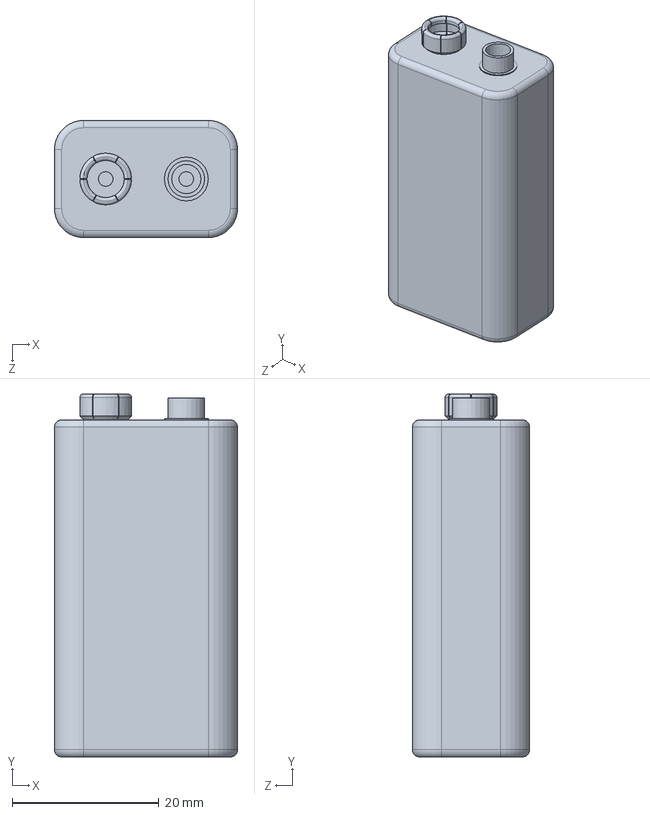
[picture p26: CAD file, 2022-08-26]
Design Pitch Artefacts/Design Consideration and Prototyping Artefacts/Phase B/Physical Collar Design/9V-2.SLDPRT
25.0 x 49.5 x 16.0 mm

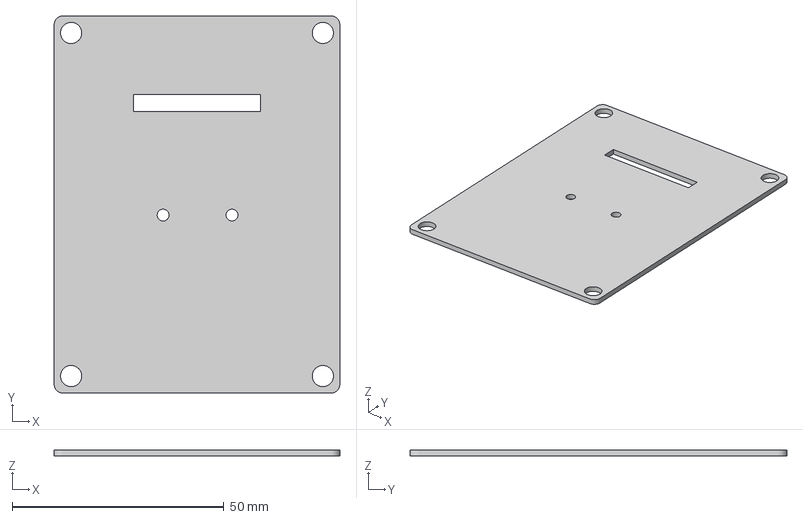
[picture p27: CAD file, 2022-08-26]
Design Milestones/Prototype/Physical Collar Design/Second layer v19.3mf
67.4 x 89.0 x 1.50 mm

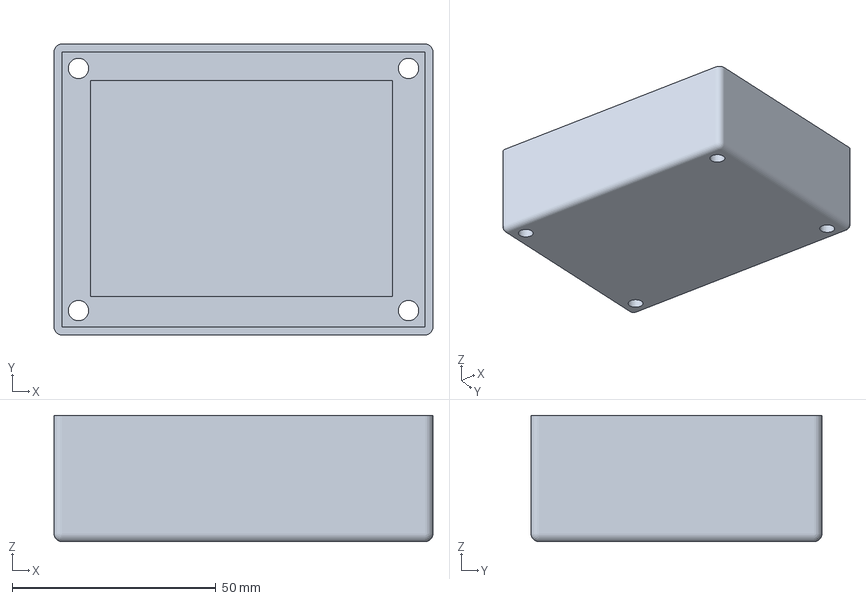
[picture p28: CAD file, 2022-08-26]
Design Pitch Artefacts/Design Consideration and Prototyping Artefacts/Phase B/Physical Collar Design/SUB_FINALTOP.3mf
92.9 x 71.4 x 31.0 mm

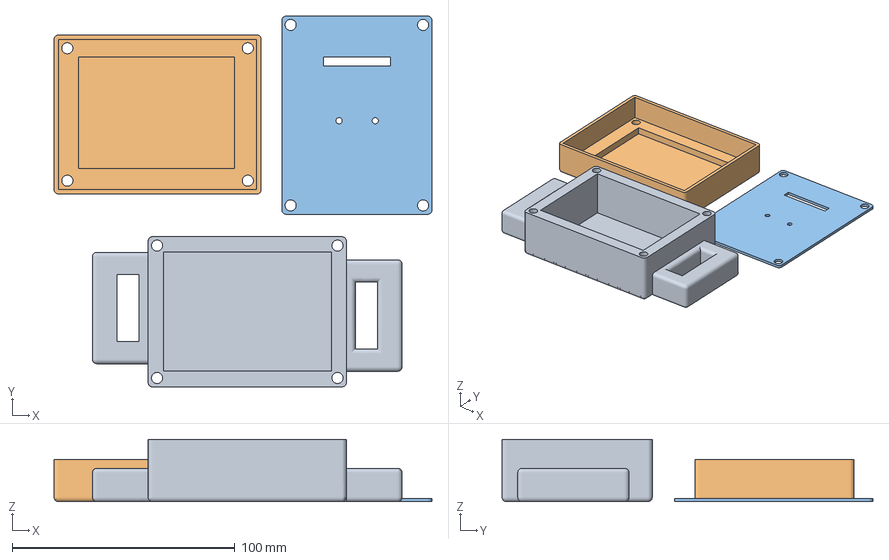
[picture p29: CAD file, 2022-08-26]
Design Pitch Artefacts/Design Consideration and Prototyping Artefacts/Phase B/Physical Collar Design/submitted version.3mf
169.6 x 166.4 x 28.0 mm
outer shell
COVER v19
Second layer v19

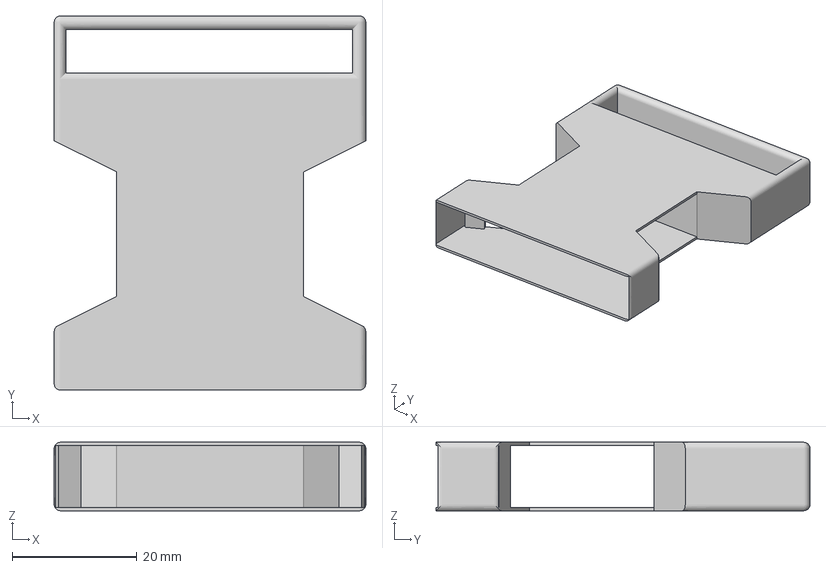
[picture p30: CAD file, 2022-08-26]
Design Milestones/Prototype/Physical Collar Design/Buckle Head.3mf
50.0 x 60.0 x 11.0 mm

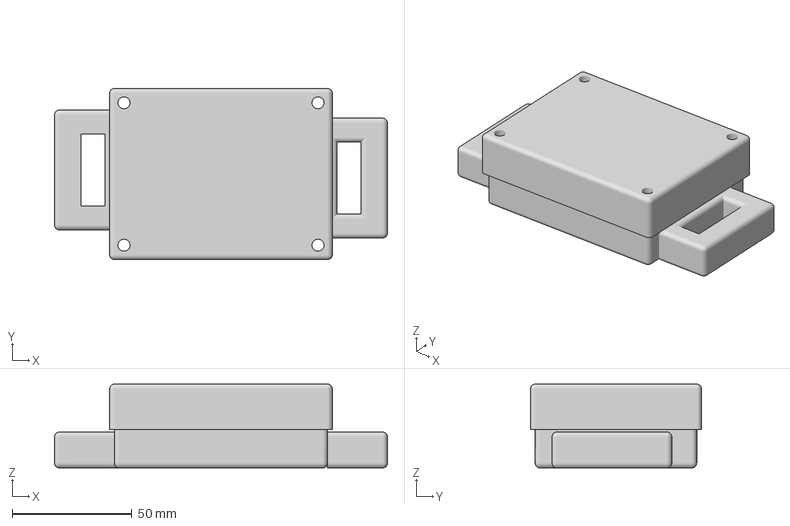
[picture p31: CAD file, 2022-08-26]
Design Milestones/Prototype/Physical Collar Design/BASE_NEW v53.3mf
138.9 x 71.4 x 35.0 mm
outer shell

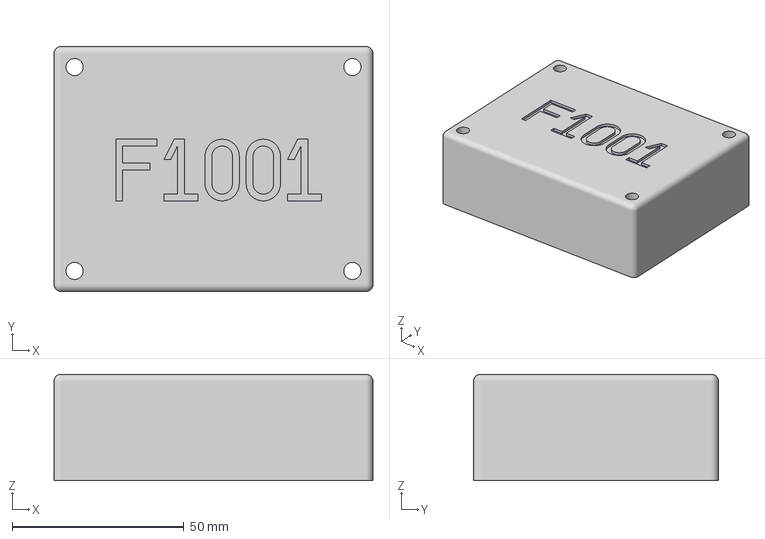
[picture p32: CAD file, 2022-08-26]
Design Milestones/Prototype/Physical Collar Design/Engraved Top.3mf
93.0 x 71.4 x 31.0 mm

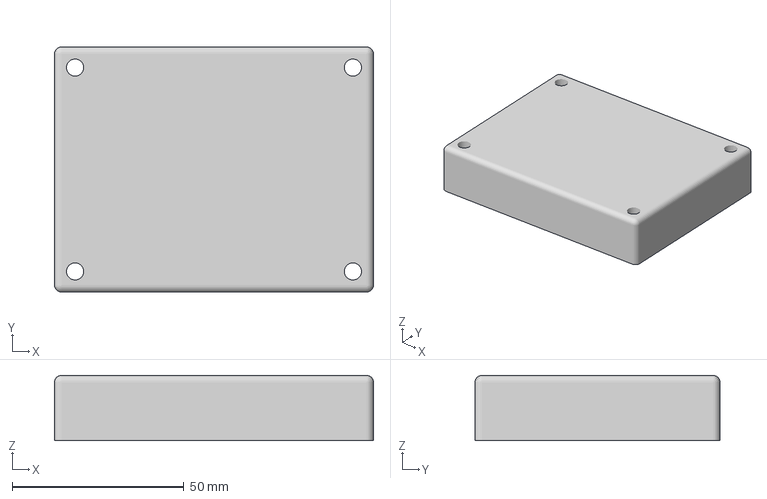
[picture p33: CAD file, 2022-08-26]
Design Pitch Artefacts/Design Consideration and Prototyping Artefacts/Phase B/Physical Collar Design/COVER v19.3mf
93.0 x 71.4 x 19.0 mm

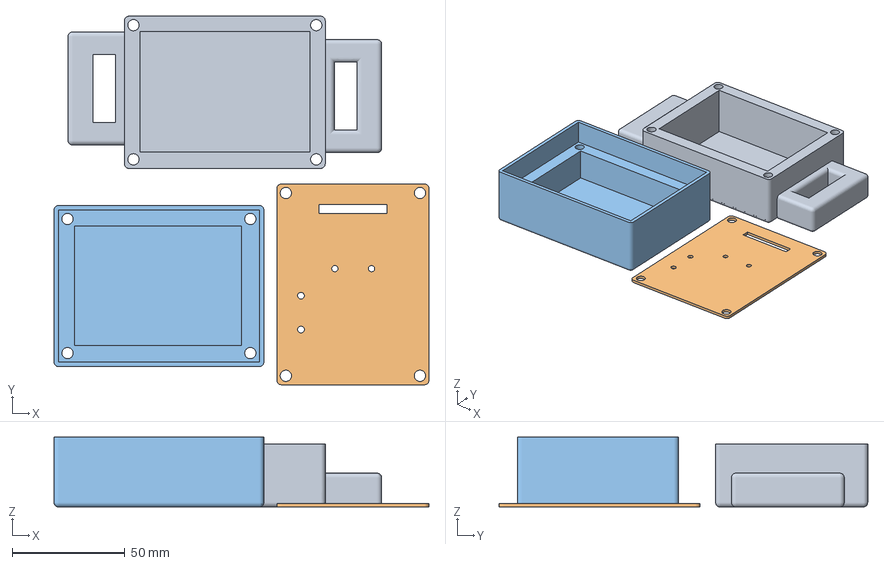
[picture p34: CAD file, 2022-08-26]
Design Pitch Artefacts/Design Consideration and Prototyping Artefacts/Phase B/Physical Collar Design/FINALSUBMITTED.3mf
166.1 x 163.3 x 31.0 mm
FINALBASE
FINALMIDDLE
FINALTOP

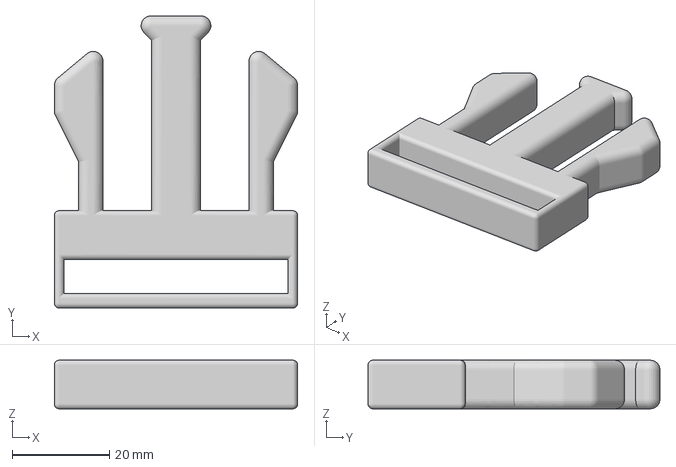
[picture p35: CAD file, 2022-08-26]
Design Pitch Artefacts/Design Consideration and Prototyping Artefacts/Phase B/Physical Collar Design/Buckle Tail.3mf
50.0 x 60.0 x 10.0 mm

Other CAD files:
Design Pitch Artefacts/Design Consideration and Prototyping Artefacts/Phase B/Physical Collar Design/FINALMIDDLE.3mf
Design Milestones/Prototype/Physical Collar Design/FINALTOP.3mf
Design Milestones/Prototype/Physical Collar Design/FINALMIDDLE.3mf
Design Milestones/Prototype/Physical Collar Design/BASE v52.3mf
Design Milestones/Phase A/Prototypes/thermal imaging+rfid tag/camera case v2.f3d
Design Milestones/Phase A/Prototypes/thermal imaging+rfid tag/thermal + barcode device v1.f3d
Design Milestones/Prototype/Physical Collar Design/50screw.3mf
Design Milestones/Prototype/Physical Collar Design/55screw.3mf
Design Milestones/Prototype/Physical Collar Design/FINALBASE.stl
Design Milestones/Prototype/Physical Collar Design/M5 Nut.3mf
Design Milestones/Prototype/Physical Collar Design/M5 SCREWS.3mf
Design Milestones/Prototype/Physical Collar Design/SUB 50screw.3mf
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

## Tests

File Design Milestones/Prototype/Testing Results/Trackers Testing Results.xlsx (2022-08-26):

RSSI Range (dBm) | Distance from leader sheep (m) | Leader Percentage (%) | Number of leader (# of sheep) | Cluster size (# of sheep) | Worest case cluster radius (m) | RSSI threshold needed (dBm) | Detected leaving successfully?
-90 | 50 | 0.100 | 15.000 | 10.000 | 22.000 | -83
-80 | 15 | 0.120 | 18.000 | 8.333 | 18.667 | -81
-75 | 8 | 0.140 | 21.000 | 7.143 | 16.286 | -79
-65 | 1.5 | 0.160 | 24.000 | 6.250 | 14.500 | -78 | 20% missed alert
-55 | 0.3 | 0.180 | 27.000 | 5.556 | 13.111
-45 | 0.1 | 0.200 | 30.000 | 5.000 | 12.000 | -76 | 20% missed alert
 |  | 0.220 | 33.000 | 4.545 | 11.091
 |  | 0.240 | 36.000 | 4.167 | 10.333
 |  | 0.260 | 39.000 | 3.846 | 9.692
 |  | 0.280 | 42.000 | 3.571 | 9.143
 |  | 0.300 | 45.000 | 3.333 | 8.667 | -74 | 10%
 |  | 0.320 | 48.000 | 3.125 | 8.250
 |  | 0.340 | 51.000 | 2.941 | 7.882
 |  | 0.360 | 54.000 | 2.778 | 7.556
 |  | 0.380 | 57.000 | 2.632 | 7.263
 |  | 0.400 | 60.000 | 2.500 | 7.000 | -72 | 8%
 |  | 0.420 | 63.000 | 2.381 | 6.762
 |  | 0.440 | 66.000 | 2.273 | 6.545
 |  | 0.460 | 69.000 | 2.174 | 6.348
 |  | 0.480 | 72.000 | 2.083 | 6.167
 |  | 0.500 | 75.000 | 2.000 | 6.000 | -70 | 8%
 |  | 0.520 | 78.000 | 1.923 | 5.846

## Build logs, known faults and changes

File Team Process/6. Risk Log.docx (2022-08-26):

Risk Log

Risk | Risk Description | Status | Response
Feb. 04
Requirement cost efficiency is not clear | We could not determine the exact cost range the stakeholder could accept, which impact our way of designing. | Pending (still pending march 9) (Resolved March 23) | Current solution is to estimate the cost based on research, waiting for stakeholder’s reply. Stakeholder has responded with a price range.
Why stakeholders are so specific about tracking | To balance the cost, we assumed that tacking is not the final requirements, but a method to prevent sheep loss. We decide on that the sheep loss is the final goal. | Pending (still pending march 9) (Resolved March 23) | After consulting the FaCs and doing rigorous analysis, we believe this decision will not cause too much risk, we are still waiting for stakeholder’s response. Stakeholder has responded and tracking IS a requirement.
Mar. 9
Scoping of the widget assignment is relatively lax | We only chose to incorporate two sensors and two actuators that are relatively simple to implement | Resolved | We decided that this was acceptable as a team since we were all busy and the design does meet the requirements.
Case ordering from MyFab may take too long | Since we need to 3D print a case, we need to submit the design early | Resolved | The case was submitted and printed on time thanks to the group being aware of the risks. Also, an extension to the deadline helped to ease time troubles.
Infrared sensor has a melted cap on it | When testing sensors, faulty wiring made the sensor overheat and melt the cap. | Resolved | It was found that the sensor still worked, so it was used in the final design.
Mar 23
Waveshare GPS module does not work | There is no documentation online, and when the code was finally imported onto the pico, the GPS module was unable to position despite multiple attempts in different outdoor spaces | Resolved | The Waveshare GPS module does not work so we will attempt to use GPS tracking using the bluefruit module.
Backend database cannot function without knowledge of the data types passed through | Location data, sheep ID all have their own data types, and without the front end figured out it is hard to create a functional database | Pending GPS module completion (see above) | The backend can be completed at a later time, although awareness of this risk should put pressure on the front end completion.

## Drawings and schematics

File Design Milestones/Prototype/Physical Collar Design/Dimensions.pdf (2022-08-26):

63.4

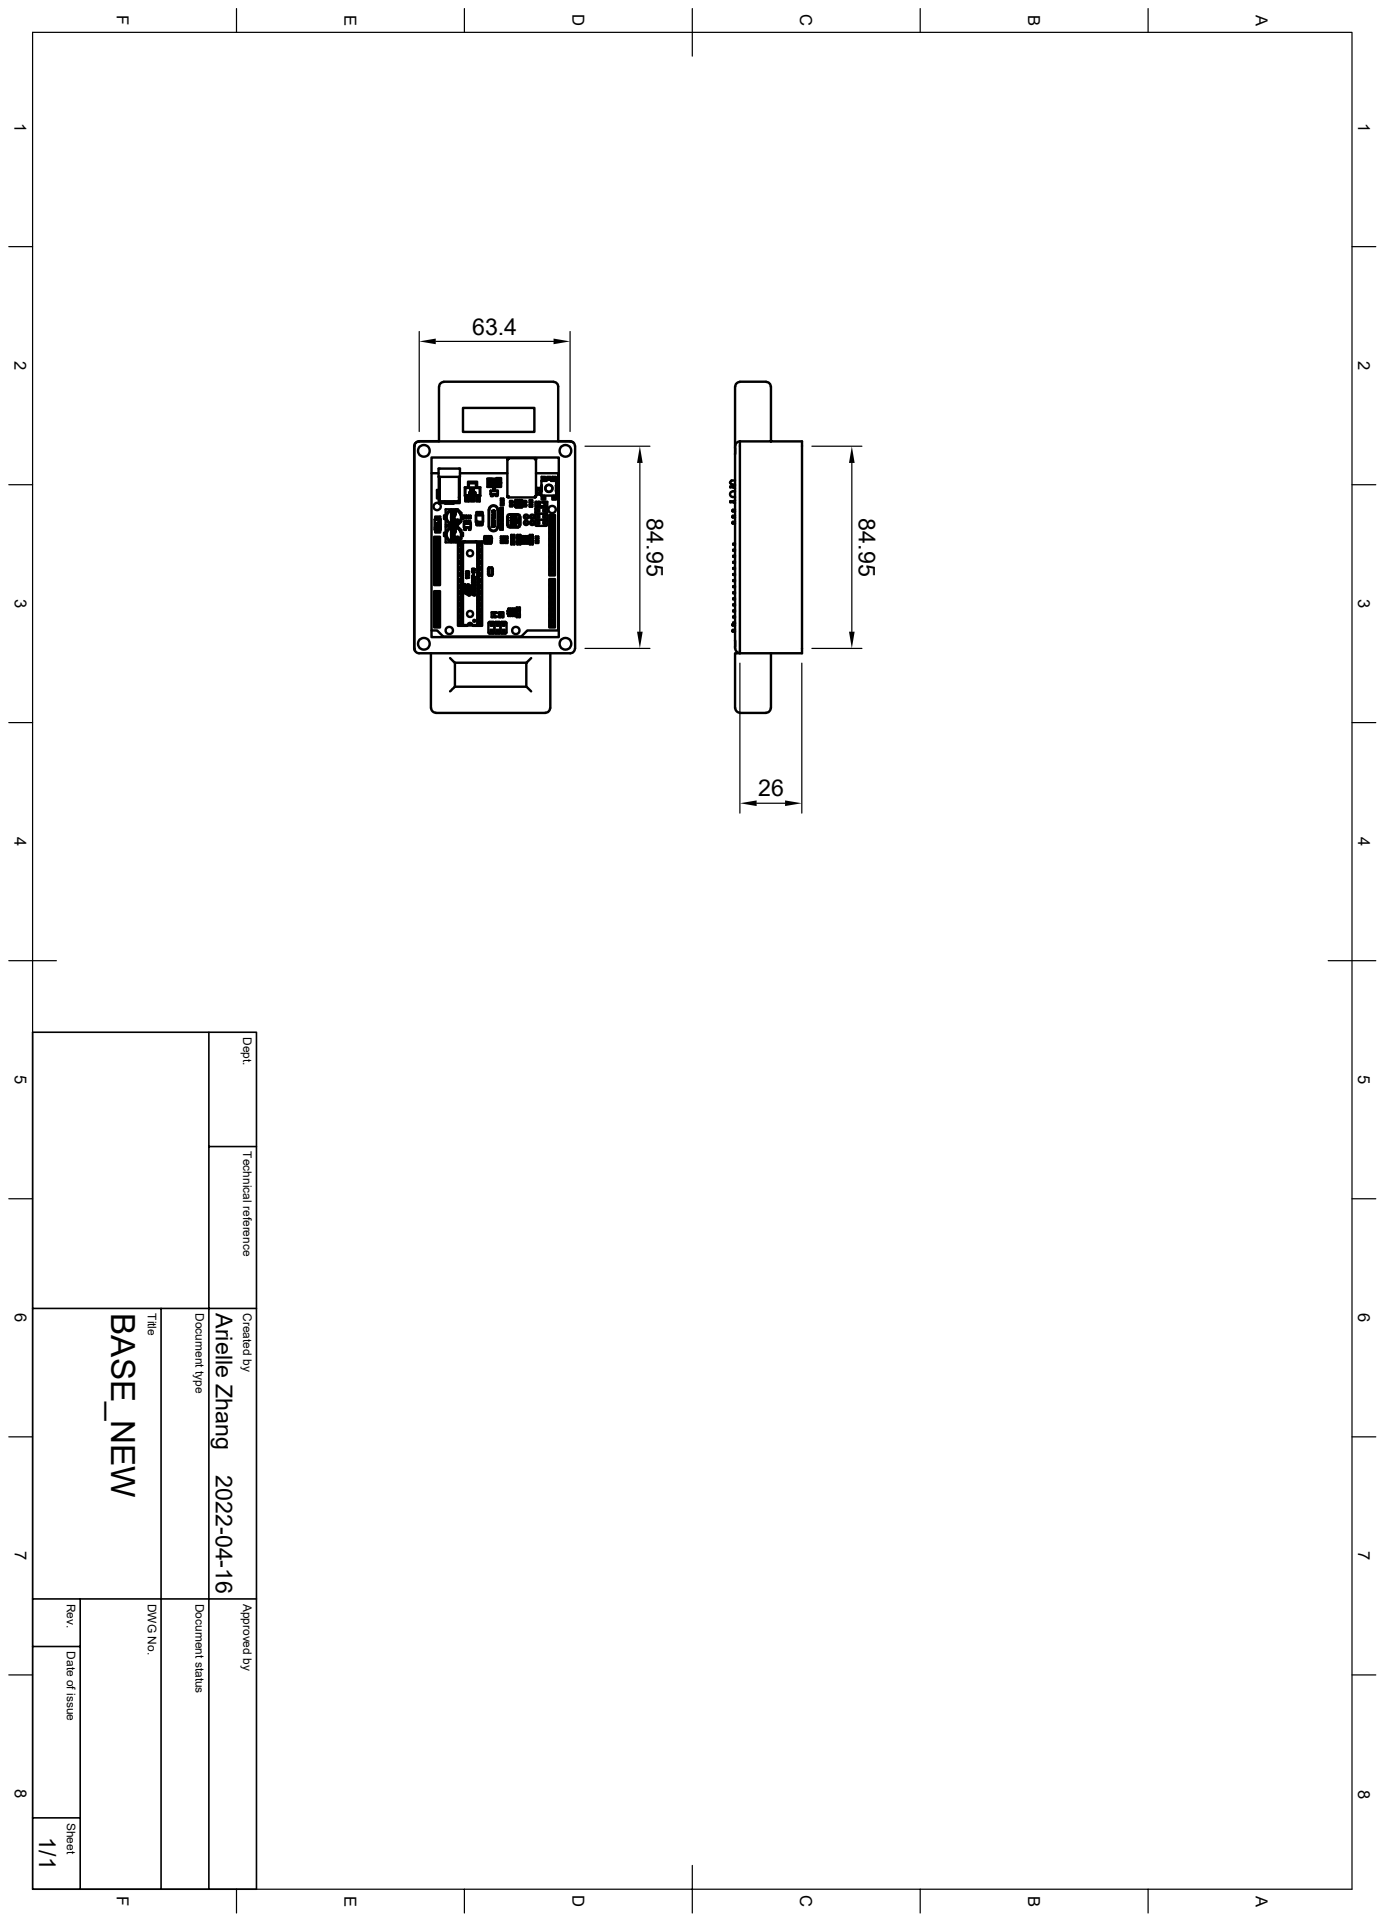
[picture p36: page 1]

1 A 2 3 4 5 6 7 8 1 2 3 4 5 6 7 8 FEDCB FEDCBA Dept. Technical reference Created by Approved by Title DWG No. Document type Document status Rev. Date of issue Sheet 2022-04-16 1/1 BASE_NEW Arielle Zhang

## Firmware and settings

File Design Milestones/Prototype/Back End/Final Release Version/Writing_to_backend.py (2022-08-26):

import sqlite3
import serial
import time
from datetime import datetime


#listens to the arduino serial monitor
def listenSerialMonitor(conn, cursor, conn2, cursor2):
    
    ser = serial.Serial('COM13', baudrate = 115200, timeout = 1)
    while True:
        time.sleep(1)
        arduinoData = ser.readline()
        print(arduinoData)
        try:
            val = arduinoData.decode("utf-8")
        except:
            pass
        print(val)
        #print(val)
        print(parseString(val, cursor))
        info = parseString(val, cursor)

        if(info != None and len(info) == 5):
            updateDB(conn, info[3], cursor, info[0], info[1], info[2], info[4])
            if(info[2][0] == "3000"):
                updateMissingSheep(cursor, info[3], conn2, cursor2)
        
        #then update the missing sheep database here

    #string format should be ULA = 17.00, LO = 36.00UL3000F3001F30040071 (last four digit starting from 1111 increase)
    #info = parseString("ULA = 22.08, LO = 38.45UL30001321", cursor)
    
    #if(info != None and len(info) == 5):
    #   updateDB(conn, info[3], cursor, info[0], info[1], info[2], info[4])
    
    #print(info[2][0])
    


    # 3 is info [3] i think
        
        #then update the missing sheep database here




            
#connects to the db
def connect(dbPath):
    conn = sqlite3.connect(dbPath)
    return conn

#gets the cursor object
def getCursor(conn):
    cursor = conn.cursor()
    return cursor

#stores all the db into the list records
def retrieveDB(cursor):
    cursor.execute("""SELECT * FROM SHEEPS;""")
    records = cursor.fetchall()
    return records

def retrieveDB2(cursor):
    cursor.execute("""SELECT * FROM MISSING;""")
    records = cursor.fetchall()
    return records

    #print(records)
#executes the given query
def executeQuery(conn, cursor, query):
    cursor.execute(query)
    conn.commit()

#updates the longitude or the langitude depending on the field
def updateDB(conn, update, cursor, lat, lon, ids, key):
        cluster = ""
        for i in ids:
            cluster = cluster + str(i)
        query = "INSERT INTO SHEEPS VALUES (" + key  + ", " + str(ids[0]) + ", " + str(lat) + ", " + str(lon) + ", " + str(cluster) + "," + str(update) +");"
        executeQuery(conn, cursor, query)
    
    



def MissingSheep(cursor, update):

    #from the database get the results
    #assume one missing sheep at a time
    cursor.execute("SELECT * FROM SHEEPS WHERE BELONGS = " + str(update) + ";")
    news = cursor.fetchall()

    cursor.execute("SELECT * FROM SHEEPS WHERE BELONGS = " + str(update-1) + ";")
    olds = cursor.fetchall()


    #first check NULL
    for new in news:
        if(len(new[4]) == 4):
            print([new[1], new[2], new[3], datetime.now().strftime("%H:%M:%S")])
            return [new[1], new[2], new[3], datetime.now().strftime("%H:%M:%S")]
    
    new_cmp = []
    old_cmp = []
    missing = ["", "", "", ""]
    missing_loc = ""

    for old in olds:
        old_clusters = []
        for a in range(len(old[4])//4):
            old_clusters.append(old[4][a*4:(a*4+4)])
        old_cmp.append(old_clusters)
                
    for new in news:       
        new_clusters = []   
        for b in range(len(new[4])//4):
            new_clusters.append(new[4][b*4:(b*4+4)])
        new_cmp.append(new_clusters)
    
    for new in new_cmp:
        for old in old_cmp:
            if new[0] == old[0]:
                for old_id in old:
                    if(not old_id in new):
                        for rec_new in new_cmp:
                            for item in rec_new:
                                if item == old_id:
                                    return
                                else:
                                    missing[0] = old_id
                                    missing[3] = datetime.now().strftime("%H:%M:%S")
                                    missing_loc = new[0]
    
    for new in news:
        if new[1] == missing_loc:
            missing[1] = new[2]
            missing[2] = new[3]
    
    return missing


def updateMissingSheep(cursor, update, conn2, cursor2):
    missing = MissingSheep(cursor, update)
    print(missing)
    if(not missing[0] == ""):
        query = "INSERT INTO MISSING VALUES ("+ missing[0] + ',' + str(missing[1]) + ','+ str(missing[2]) + ',' + "'" + missing[3] + "'" + ");"
        print(query)
        executeQuery(conn2, cursor2, query)





def parseString(string, cursor):
    if(len(string) > 0 and string[0] == 'U'):
        key = string[-5:-1]
        print(key)
        string = string[0:-6]
        a = string.split('U')
        coord_str = a[1]
        c = coord_str.split('=')
        lat = c[1].split(',')[0][1:]
        lon = c[2][1:]
        id_str = a[2]
        ids = id_str[1:].split('F')
        cursor.execute("SELECT * FROM SHEEPS WHERE OWNER = " + str(ids[0]) + ";")
        records = cursor.fetchall()
        print(records)

        update = 1 + records[-1][-1]
        print(update)
        print([lat,lon,ids, update, key])##
        return [lat,lon,ids, update, key]


if __name__ == '__main__':
    #path = 'C:\\Users\\emrec\\OneDrive\\Desktop\\database.db'
    #path2 = 'C:\\Users\\emrec\\OneDrive\\Desktop\\missing.db'
    #path = "E:\\University of Toronto\\FASE ESC Praxis III Teaching Team - 2022 Winter - Student Work - Team 1034A\\Design Milestones\\Prototype\\Back End\\ReleaseVersion\\database.db"
    #path2 = "E:\\University of Toronto\\FASE ESC Praxis III Teaching Team - 2022 Winter - Student Work - Team 1034A\\Design Milestones\\Prototype\\Back End\\ReleaseVersion\\missing.db"
    path = "database.db"
    path2 = "missing.db"

    conn = connect(path)
    cursor = getCursor(conn)

    conn2 = connect(path2)
    cursor2 = getCursor(conn2)

    #executeQuery(conn, cursor, """UPDATE SHEEPS SET CLUSTER = '1001 1002' WHERE ID = 1000""")
    #executeQuery(conn2, cursor2, """INSERT INTO MISSING VALUES (1003, 4.3, 5.2, '12:54:13')""")
    #db = retrieveDB(cursor)
    #print(missingSheep(db))
    #updateMissing(conn2, cursor, cursor2)
    listenSerialMonitor(conn, cursor, conn2, cursor2)

    #parseString('UPDATE_LATITUDE = 17.911847, LONGITUDE = 36.436322_L1000F1001F1002F1003F1004F1005')

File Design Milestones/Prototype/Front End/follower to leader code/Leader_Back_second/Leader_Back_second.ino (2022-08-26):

/*********************************************************************
 This is an example for our nRF51822 based Bluefruit LE modules

 Pick one up today in the adafruit shop!

 Adafruit invests time and resources providing this open source code,
 please support Adafruit and open-source hardware by purchasing
 products from Adafruit!

 MIT license, check LICENSE for more information
 All text above, and the splash screen below must be included in
 any redistribution
*********************************************************************/

#include <Arduino.h>
#include <SPI.h>
#include "Adafruit_BLE.h"
#include "Adafruit_BluefruitLE_SPI.h"
#include "Adafruit_BluefruitLE_UART.h"

#include "BluefruitConfig.h"

#if SOFTWARE_SERIAL_AVAILABLE
  #include <SoftwareSerial.h>
#endif

/*=========================================================================
    APPLICATION SETTINGS

    FACTORYRESET_ENABLE       Perform a factory reset when running this sketch
   
                              Enabling this will put your Bluefruit LE module
                              in a 'known good' state and clear any config
                              data set in previous sketches or projects, so
                              running this at least once is a good idea.
   
                              When deploying your project, however, you will
                              want to disable factory reset by setting this
                              value to 0.  If you are making changes to your
                              Bluefruit LE device via AT commands, and those
                              changes aren't persisting across resets, this
                              is the reason why.  Factory reset will erase
                              the non-volatile memory where config data is
                              stored, setting it back to factory default
                              values.
       
                              Some sketches that require you to bond to a
                              central device (HID mouse, keyboard, etc.)
                              won't work at all with this feature enabled
                              since the factory reset will clear all of the
                              bonding data stored on the chip, meaning the
                              central device won't be able to reconnect.
    MINIMUM_FIRMWARE_VERSION  Minimum firmware version to have some new features
    MODE_LED_BEHAVIOUR        LED activity, valid options are
                              "DISABLE" or "MODE" or "BLEUART" or
                              "HWUART"  or "SPI"  or "MANUAL"
    -----------------------------------------------------------------------*/
    #define FACTORYRESET_ENABLE         0
    #define MINIMUM_FIRMWARE_VERSION    "0.6.6"
    #define MODE_LED_BEHAVIOUR          "MODE"
/*=========================================================================*/

// Create the bluefruit object, either software serial...uncomment these lines

SoftwareSerial bluefruitSS = SoftwareSerial(BLUEFRUIT_SWUART_TXD_PIN, BLUEFRUIT_SWUART_RXD_PIN);

Adafruit_BluefruitLE_UART ble(bluefruitSS, BLUEFRUIT_UART_MODE_PIN,
                      BLUEFRUIT_UART_CTS_PIN, BLUEFRUIT_UART_RTS_PIN);


/* ...or hardware serial, which does not need the RTS/CTS pins. Uncomment this line */
// Adafruit_BluefruitLE_UART ble(Serial1, BLUEFRUIT_UART_MODE_PIN);

/* ...hardware SPI, using SCK/MOSI/MISO hardware SPI pins and then user selected CS/IRQ/RST */
//Adafruit_BluefruitLE_SPI ble(BLUEFRUIT_SPI_CS, BLUEFRUIT_SPI_IRQ, BLUEFRUIT_SPI_RST);

/* ...software SPI, using SCK/MOSI/MISO user-defined SPI pins and then user selected CS/IRQ/RST */
//Adafruit_BluefruitLE_SPI ble(BLUEFRUIT_SPI_SCK, BLUEFRUIT_SPI_MISO,
//                             BLUEFRUIT_SPI_MOSI, BLUEFRUIT_SPI_CS,
//                             BLUEFRUIT_SPI_IRQ, BLUEFRUIT_SPI_RST);


// A small helper
void error(const __FlashStringHelper*err) {
  Serial.println(err);
  while (1);
}

/**************************************************************************/
/*!
    @brief  Sets up the HW an the BLE module (this function is called
            automatically on startup)
*/
/**************************************************************************/
void setup(void)
{
  while (!Serial);  // required for Flora & Micro
  delay(500);

  Serial.begin(115200);
  //Serial.println(F("Adafruit Bluefruit Command Mode Example"));
  //Serial.println(F("---------------------------------------"));

  /* Initialise the module */
  //Serial.print(F("Initialising the Bluefruit LE module: "));

  if ( !ble.begin(VERBOSE_MODE) )
  {
    error(F("Couldn't find Bluefruit, make sure it's in CoMmanD mode & check wiring?"));
  }
  Serial.println( F("OK!") );

  if ( FACTORYRESET_ENABLE )
  {
    /* Perform a factory reset to make sure everything is in a known state */
    Serial.println(F("Performing a factory reset: "));
    if ( ! ble.factoryReset() ){
      error(F("Couldn't factory reset"));
    }
  }

  /* Disable command echo from Bluefruit */
  //ble.echo(false);

  //Serial.println("Requesting Bluefruit info:");
  /* Print Bluefruit information */
  //ble.info();

  //Serial.println(F("Please use Adafruit Bluefruit LE app to connect in UART mode"));
  //Serial.println(F("Then Enter characters to send to Bluefruit"));
 // Serial.println();

  ble.verbose(false);  // debug info is a little annoying after this point!

  /* Wait for connection */
  while (! ble.isConnected()) {
      delay(500);
  }

  // LED Activity command is only supported from 0.6.6
  if ( ble.isVersionAtLeast(MINIMUM_FIRMWARE_VERSION) )
  {
    // Change Mode LED Activity
    //Serial.println(F("******************************"));
    Serial.println(F("Change LED activity to " MODE_LED_BEHAVIOUR));
    ble.sendCommandCheckOK("AT+HWModeLED=" MODE_LED_BEHAVIOUR);
   // Serial.println(F("******************************"));
  }
}

/**************************************************************************/
/*!
    @brief  Constantly poll for new command or response data
*/
/**************************************************************************/
void loop(void)
{
  // Check for user input
  char inputs[BUFSIZE+1];

  if ( getUserInput(inputs, BUFSIZE) )
  {
    // Send characters to Bluefruit
    Serial.print("[Send] ");
    Serial.println(inputs);

    ble.print("AT+BLEUARTTX=");
    ble.println(inputs);

    // check response stastus
    if (! ble.waitForOK() ) {
      Serial.println(F("Failed to send?"));
    }
  }

  // Check for incoming characters from Bluefruit
  ble.println("AT+BLEUARTRX");
  ble.readline();
  if (strcmp(ble.buffer, "OK") == 0) {
    // no data
    return;
  }
  // Some data was found, its in the buffer
  Serial.println(ble.buffer);
  ble.waitForOK();
}
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
